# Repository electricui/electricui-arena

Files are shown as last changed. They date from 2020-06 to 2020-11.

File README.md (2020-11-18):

# Electric UI CI Arena
Hardware for continuous integration testing of serial interfaces and microcontrollers. [Background and more detailed discussion outlined in this blog post](https://electricui.com/blog/hardware-testing).

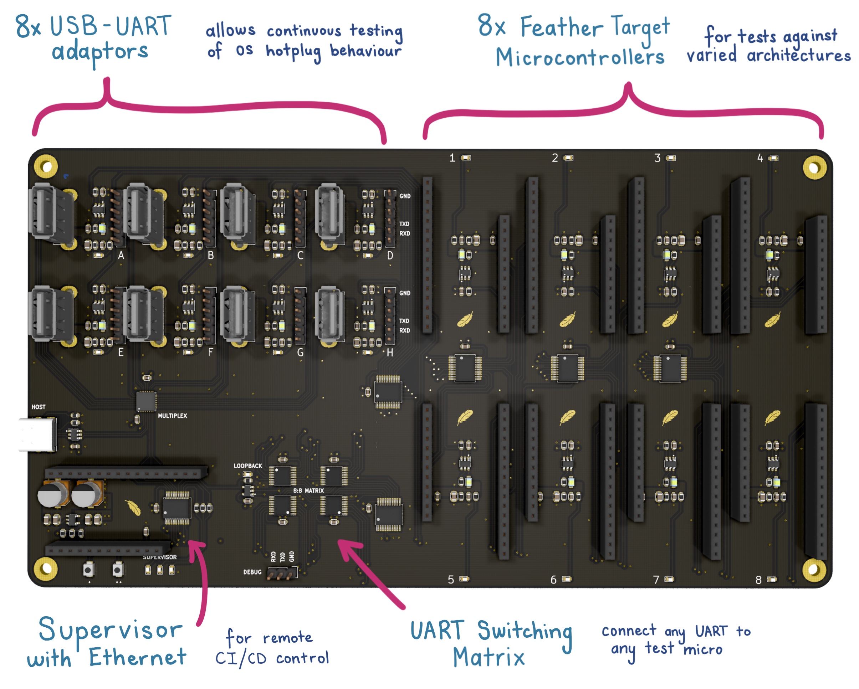
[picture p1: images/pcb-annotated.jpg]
PCB Render with annotations


The board (KiCAD files in `/hardware`) exposes control to a CI build worker to power up any of the USB-UART adaptors in either loopback mode, or connected to any **one** of the hardware targets for a total test matrix of 72 combinations. 

Intended to run tests for hot-plug detection (by controlling the mux or USB power control), disconnection handling (by re-routing serial to the void) and to validate a wide range of microcontroller architectures and their corresponding toolchains.

## USB to UART Validation

Up to 8 USB ports are provided behind a USB mux from the host.

Individual power switching is available per-port, with optional routing of the USB-UART adaptor's serial lines to either loop-back, or to one of the target microcontrollers.

The following adaptors are used as test adaptors:

- [FT232RQ](https://www.sparkfun.com/products/9717)
- PL2303
- [CP2012](https://www.adafruit.com/product/954)
- CH340G

In the future, we hope to add Bluetooth/WiFi adaptors for wireless tests against compatible targets.

## Microcontroller Validation

8 power-switched targets are supported with connections to hardware serial. The [Adafruit Feather specification](https://learn.adafruit.com/adafruit-feather/feather-specification) is used, as a majority of planned targets are available in Feather format.

The following boards are used as test devices:

- [ATMEL 328P](https://www.adafruit.com/product/3458)
- [ATMEL SAMD21G](https://www.adafruit.com/product/2772)
- [ST STM32F405](https://www.adafruit.com/product/4382) with CubeHAL
- [Nordic nRF52840](https://www.adafruit.com/product/4516) 
- [RISC-V FE310](https://www.sparkfun.com/products/15799) with Zephyr RTOS
- [Ambiq Apollo3 ARM-M4F (Sparkfun Artemis)](https://www.sparkfun.com/products/15574) 
- [Espressif ESP32](https://www.sparkfun.com/products/15663) with ESP-IDF
- [Teensy 3.2](https://www.pjrc.com/store/teensy32.html) & [Teensy-Feather adaptor](https://www.adafruit.com/product/3200) with Arduino

Test hardware will be flashed with a mix of native 'bare metal' images, and at least one target will act as validation of the Arduino framework.

When populating the test Feather boards with headers, use 'stacking' headers to allow for future sensor/display additions to targets.

## Supervisory Control

An additional Feather is provided to act as the supervisor. This connects to the CI server using a [ethernet featherwing](https://www.adafruit.com/product/3201).

The supervisor (through I2C expanders) controls power switches to each of the serial adaptors and test devices, and has 2 IO lines to each microcontroller to allow for input/output checks.

An analog line is shared across all modules, with the intent of using the supervisor's DAC output, allowing additional tests.

Firmware is in `/firmware`

# Manufacture

- I used JLPCB's 4-layer JLC7628 controlled impedance process.
- No stencil was ordered, as 2 units with low SMD part count is easy enough to paste by hand.
- All components were available from Digikey.
- Microcontroller targets were bought from Sparkfun and Adafruit (via Digikey)
- Assembled per board costs just under $100AUD.
- Loaded price (with listed microcontrollers, USB-serial adaptors, supervisor w ethernet) approx $500AUD.

See `/hardware/output/arena-BOM.html` for PCB BOM.

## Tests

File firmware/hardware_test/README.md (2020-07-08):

# Arduino Firmware Notes

Written against a [Adafruit ESP32 Feather](https://www.adafruit.com/product/3405), and [Adafruit Ethernet Featherwing](https://www.adafruit.com/product/3201) with the backplane PCB in this repo.

A reasonably thin GPIO abstraction layer maps enum named pins to the expander and pin on the board.

## Fimware Deps

A from-scratch driver for the MCP23008 I2C expanders is included in the sources instead of pulling a 3rd party one.

All 3rd party dependancies are for networking.

### Ethernet 

The ethernet Featherwing uses the [Arduino `Ethernet` library](https://github.com/arduino-libraries/Ethernet) which can be installed through the Arduino IDE board manager.

Due to an upstream `esp32-arduino-core` [change](https://github.com/arduino-libraries/Ethernet/issues/88), `EthernetServer` fails to build with the following error:

```
 error: cannot declare variable 'server' to be of abstract type 'EthernetServer'
```

I applied the changes [outlined in this open PR](https://github.com/arduino-libraries/Ethernet/pull/107/commits/81c2ce0c6922fc984703bf3adeacaf73bcc3f578).

### mDNS / Bonjour

Uses the [EthernetBonjour](https://github.com/TrippyLighting/EthernetBonjour) library.

### HTTP/REST

This [HTTPserver](https://github.com/nickgammon/HTTPserver) library makes handling the REST style API a bit less painful.

### Config Storage

User-configurable settings are maintained on the ESP32 supervisor micro using `Preferences.h` which is provided alongside the rest of the ESP32 hal.

# API Documentation

Valid requests will return as `200 OK`, with relevant text in the body, typically echoing the request.

If an invalid request is made, a `500 Internal Server Error` will be returned with some debug text in the body.

All data for GET or POST is assumed to be string formatted.

## Requests

Purely used to query the board for information.

| GET URL | Description | Response |
| --- | --- | --- |
| `arena.local/loopback?` | Serial Matrix Loopback enabled | `true`/`false` |
| `arena.local/adapter?` | List the stored human-friendly USB adapters | `a, ftdi`<br />`b, cp2012`<br />...<br />`h, pl232` |
| `arena.local/adapter?b` | Human-friendly name of a specified adapter | `ch340` |
| `arena.local/adapter?ch340` | Board labelled name of a human-readable adapter name | `b` |
| `arena.local/target?` | List the stored human-friendly device names | `1, riscv`<br />`2, stm32`<br />...<br />`8, avr` |
| `arena.local/target?2` | Human-friendly name of a specified target | `stm32` |
| `arena.local/target?stm32`  | Board labelled name of a human-readable target name  | `2` |
| `arena.local/config?name` | Get the name of the test board | `Arena Testbed` as default, otherwise a string as configured. |

## Control

HTTP POST are used to set the active adapter, target, and loopback mode. The data/payload is assumed to be string formatted.

When setting a target or adapter, the firmware will automatically setup the relevant side of the USB mux, power control, and serial matrix routing as required.

| POST URL | Data | Description | Response |
| --- | --- | --- | --- |
| `arena.local/adapter`  | `ft232` | Select the active USB Serial adapter by human-readable name | `ft232` |
| `arena.local/adapter`  | `a` | Select the active USB Serial adapter by board-label | `a` |
| `arena.local/adapter`  | `a=ft232` | Sets the human-readable name of `a` to `ft232` | `Adapter name set` |
| `arena.local/target` | `stm32` | Select the active test device by human-readable name | `stm32` |
| `arena.local/target` | `3` | Select the active test device by board-label | `3` |
| `arena.local/target` | `1=riscv` | Sets the human-readable name of `1` to `riscv` | `Device name set`  |
| `arena.local/loopback` | `true` | Enable the serial loopback switch | `true` |
| `arena.local/loopback` | `false` | Disable the serial loopback switch | `false` |
| `arena.local/config` | `name=Dave` | Sets the board's name to `Dave` | `Board name set` |

## Examples

- Select the 8th target device: `curl -X POST http://arena.local/target -d 8`

- Select a target called stm32: `curl -X POST http://arena.local/target -d stm32`

- Configure the human-readable name for the 2nd target to be `teensy`: `curl -X POST http://arena.local/target -d 2=teensy`

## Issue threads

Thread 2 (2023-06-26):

Link to order the assembled PCB

gshiva, 2023-06-26:
For people who find it hard to do the "simple" paste and heat of SMD components, it would be great if we have a link where we can order the preassembled board from JCB.

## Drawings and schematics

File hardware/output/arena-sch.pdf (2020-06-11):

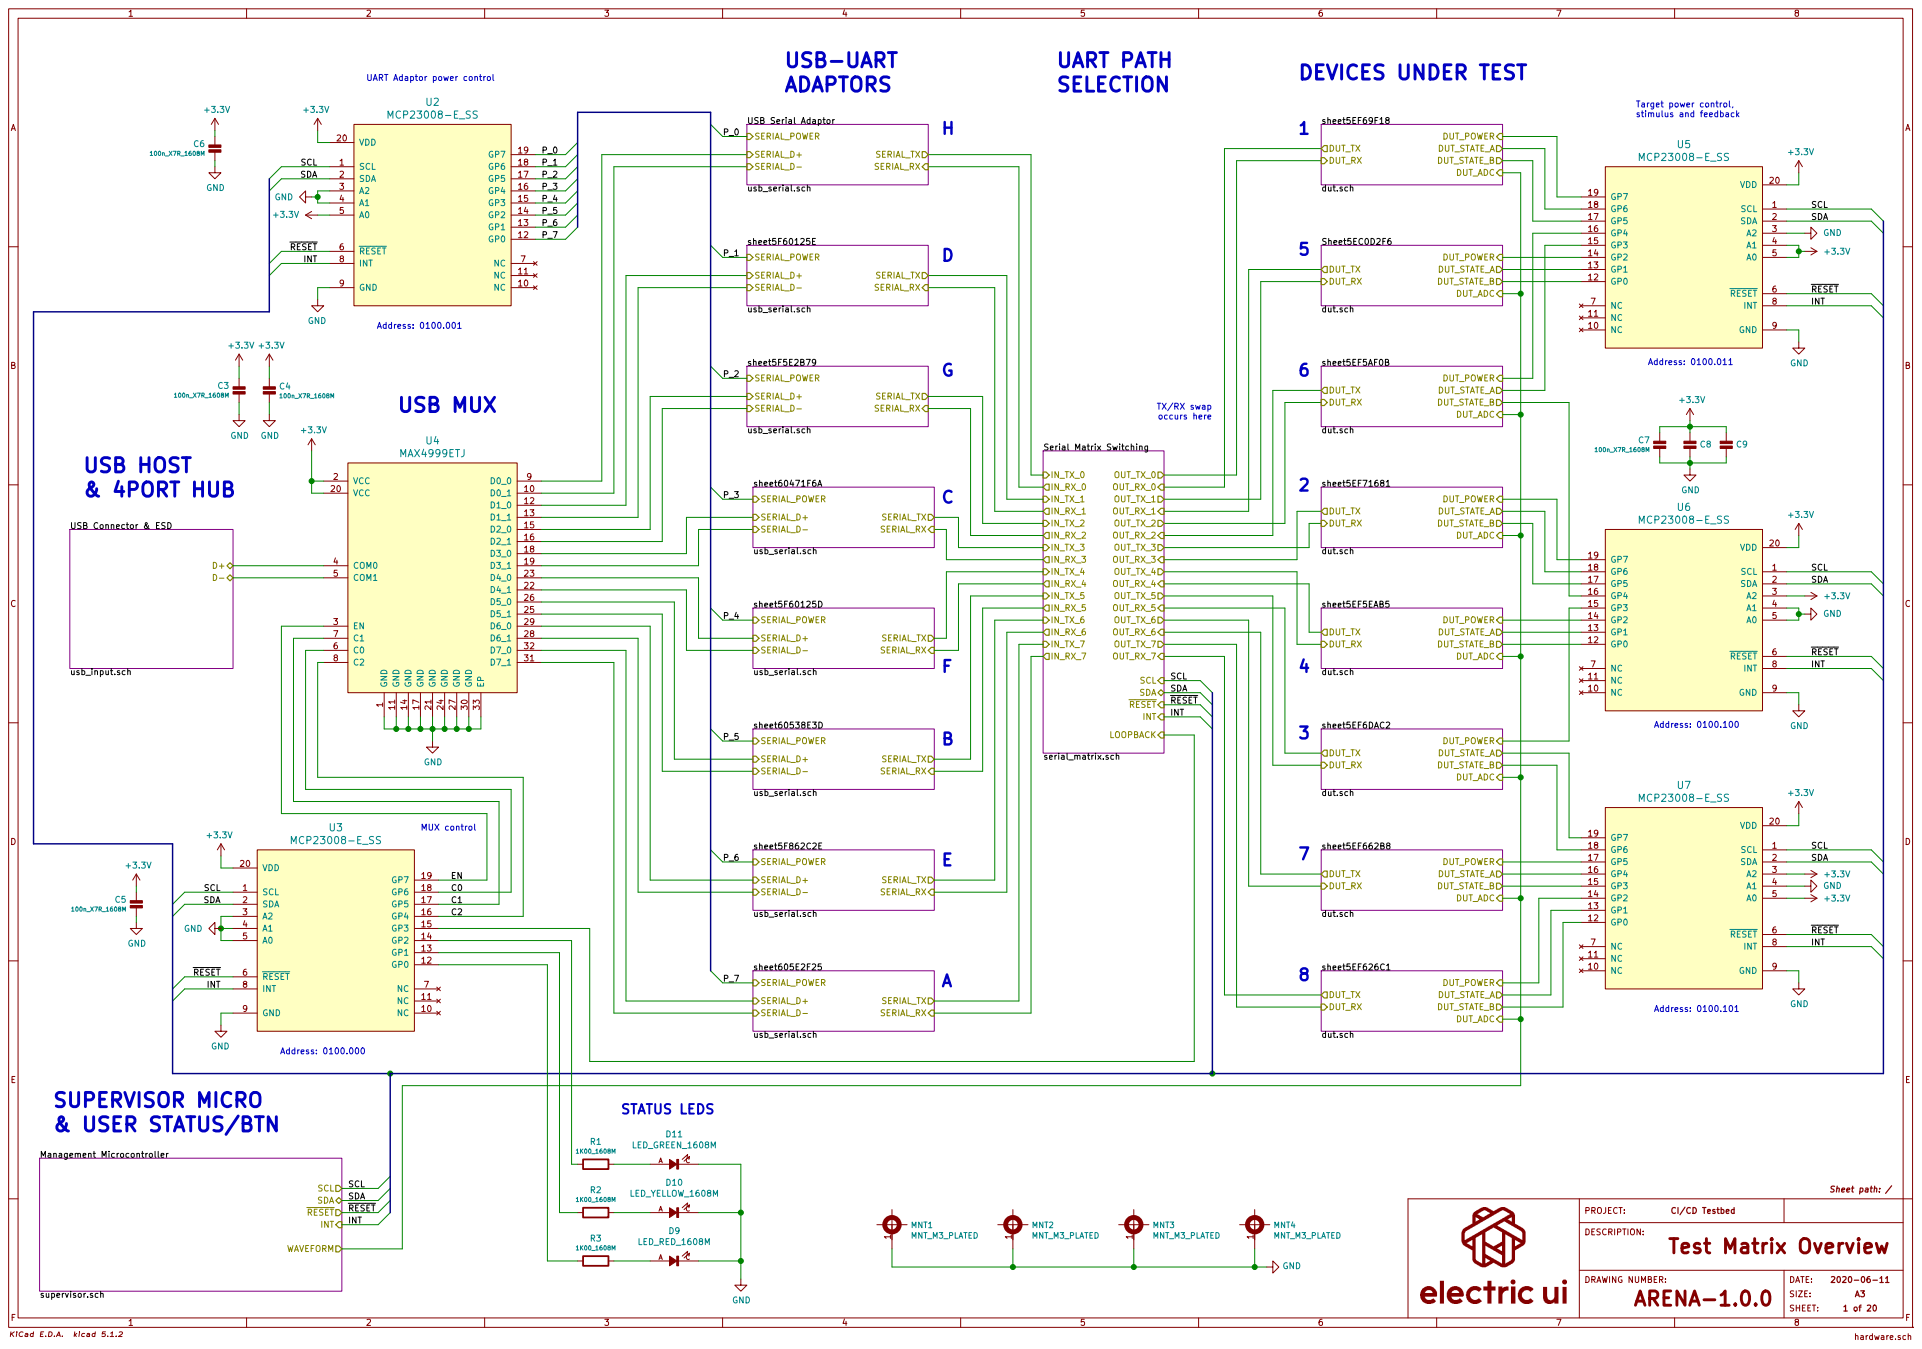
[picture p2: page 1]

DEVICES UNDER TEST UART PATH
SELECTION
SERIAL_RX USB Serial Adaptor usb_serial.sch SERIAL_POWER

ADAPTORS GND
Target power control, stimulus and feedback UART Adaptor power control

Address: 0100.101 Address: 0100.100 Address: 0100.011 SUPERVISOR MICRO

1 D0_1 10 GND 11 D1_0 12 D1_1 13 GND 14 D2_0 15 D2_1 16 GND 17 D3_0 18 D3_1 19 VCC 2 VCC 20 GND 21 D4_1 22 D4_0 23 GND 24 D5_1 25 D5_0 26 GND 27 D6_1 28 D6_0 29 EN 3 GND 30 D7_1 31 D7_0 32 EP 33 COM0 4 COM1 5 C0 6 C1 7 C2 8 D0_0 9 U4 MAX4999ETJ C4

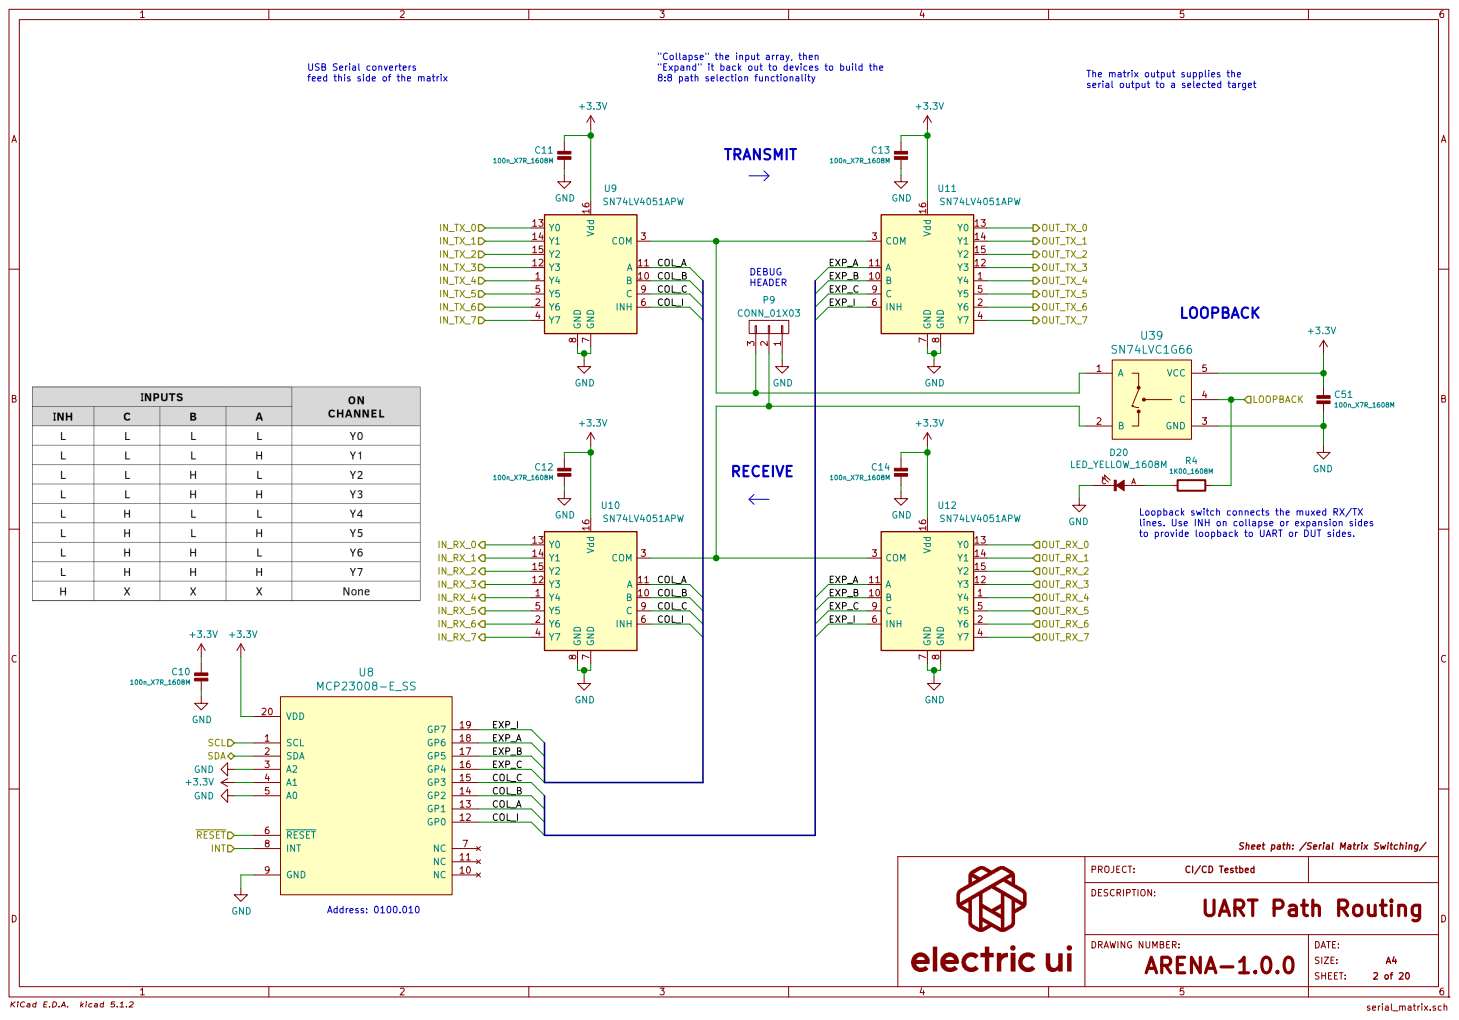
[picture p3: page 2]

"Collapse" the input array, then
"Expand" it back out to devices to build the
8:8 path selection functionality

serial output to a selected target USB Serial converters
feed this side of the matrix

The matrix output supplies the

Loopback switch connects the muxed RX/TX
lines. Use INH on collapse or expansion sides

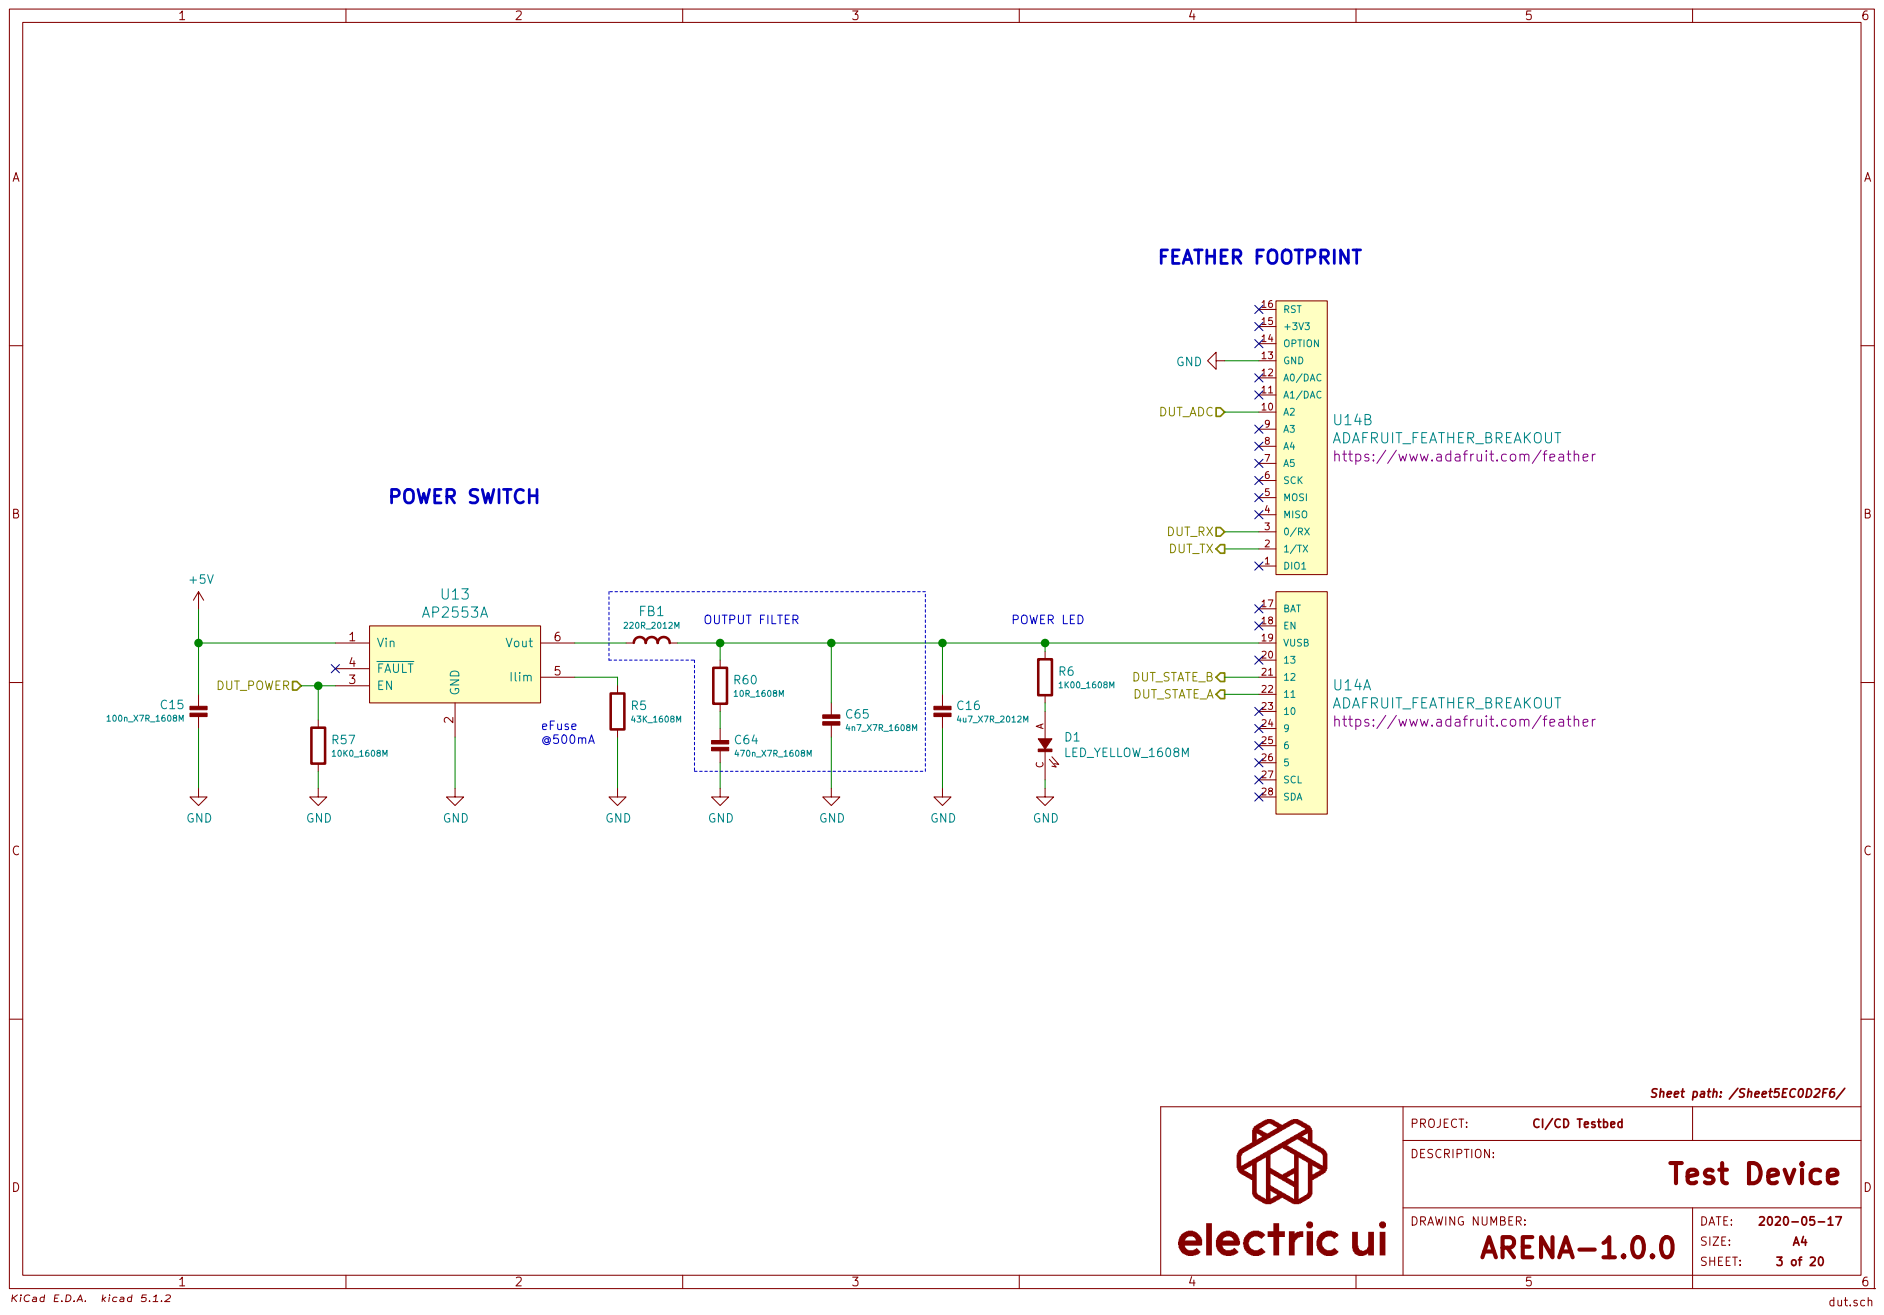
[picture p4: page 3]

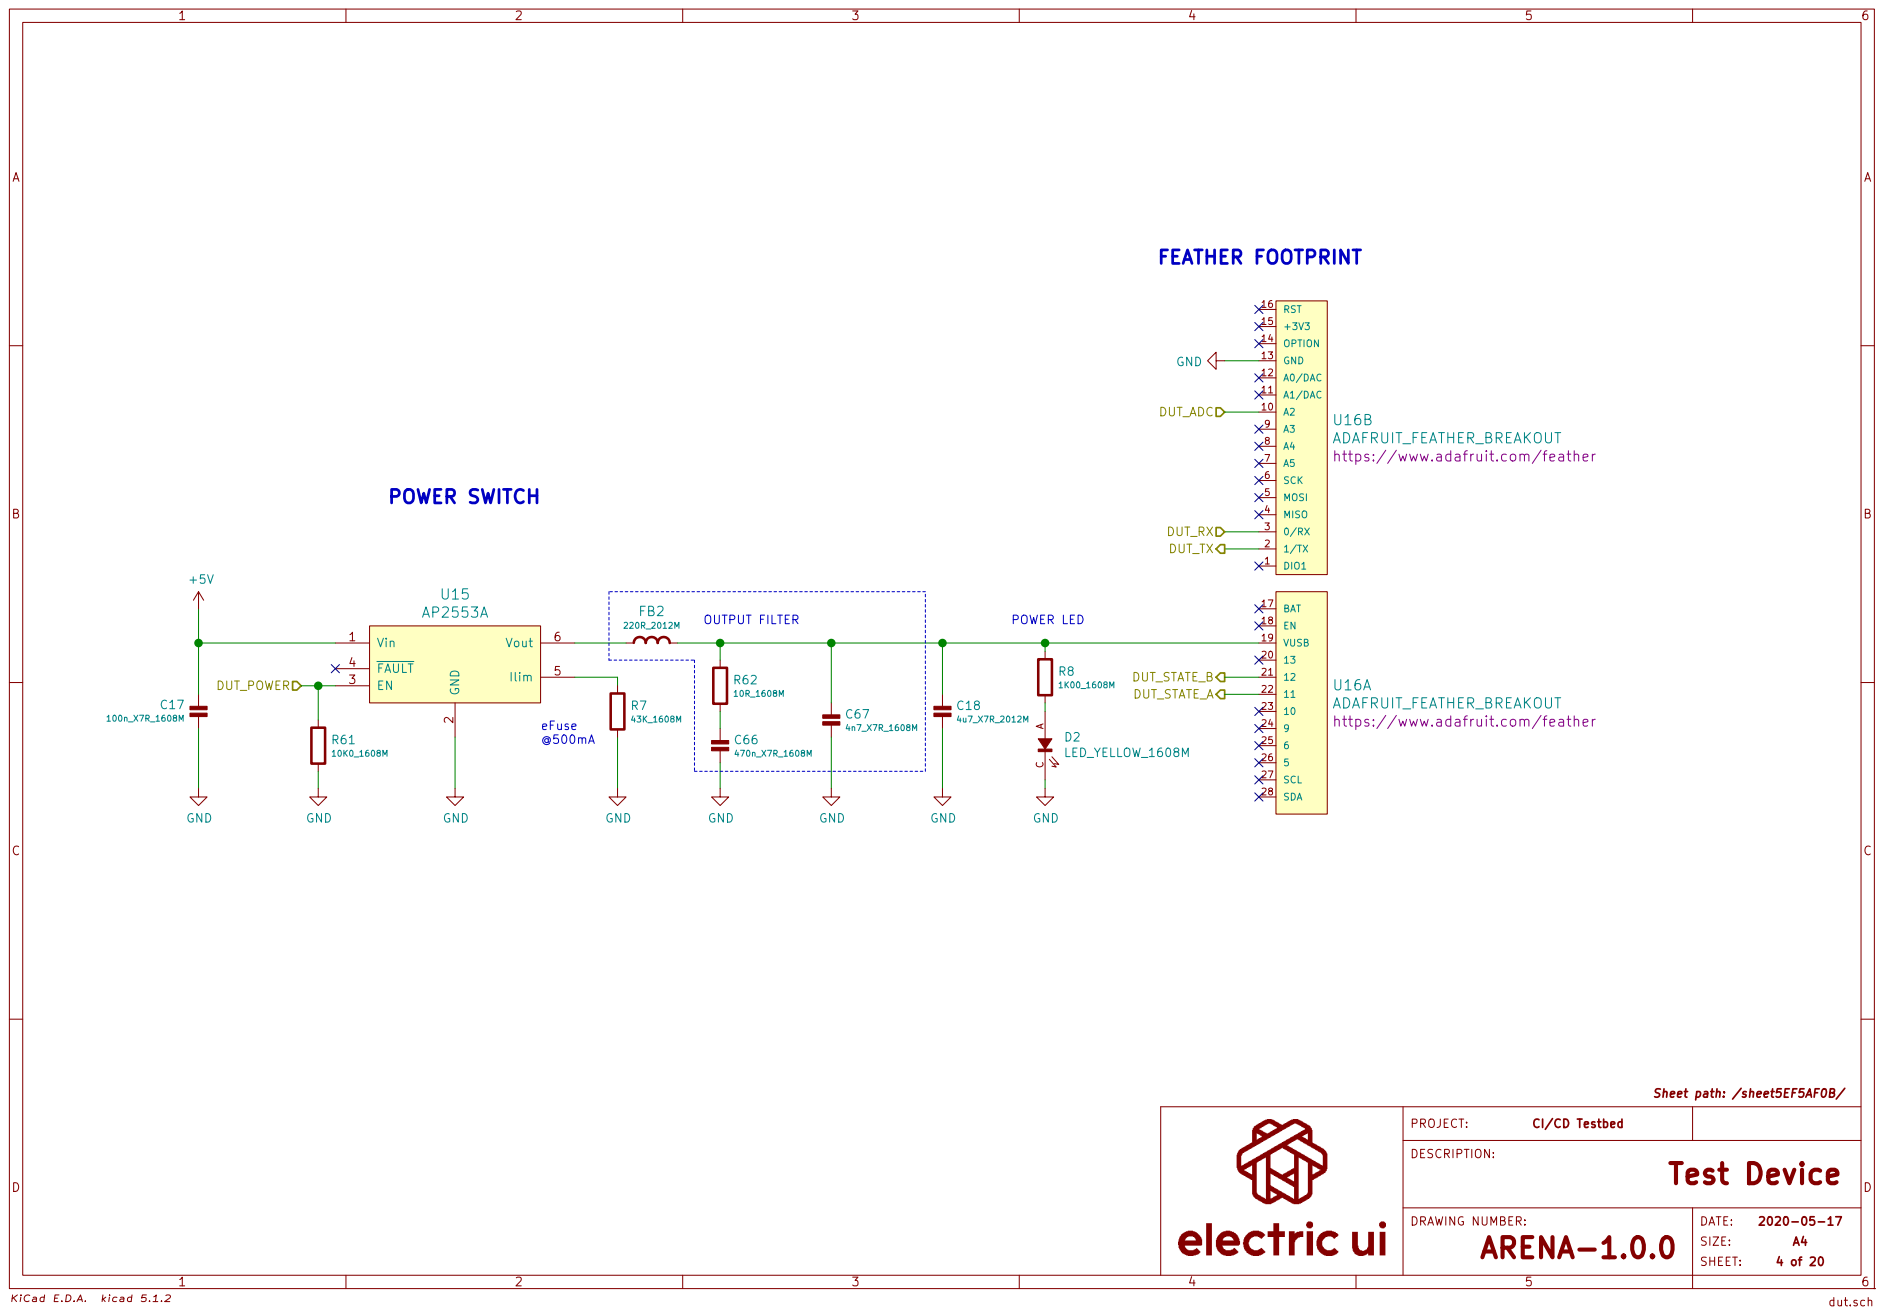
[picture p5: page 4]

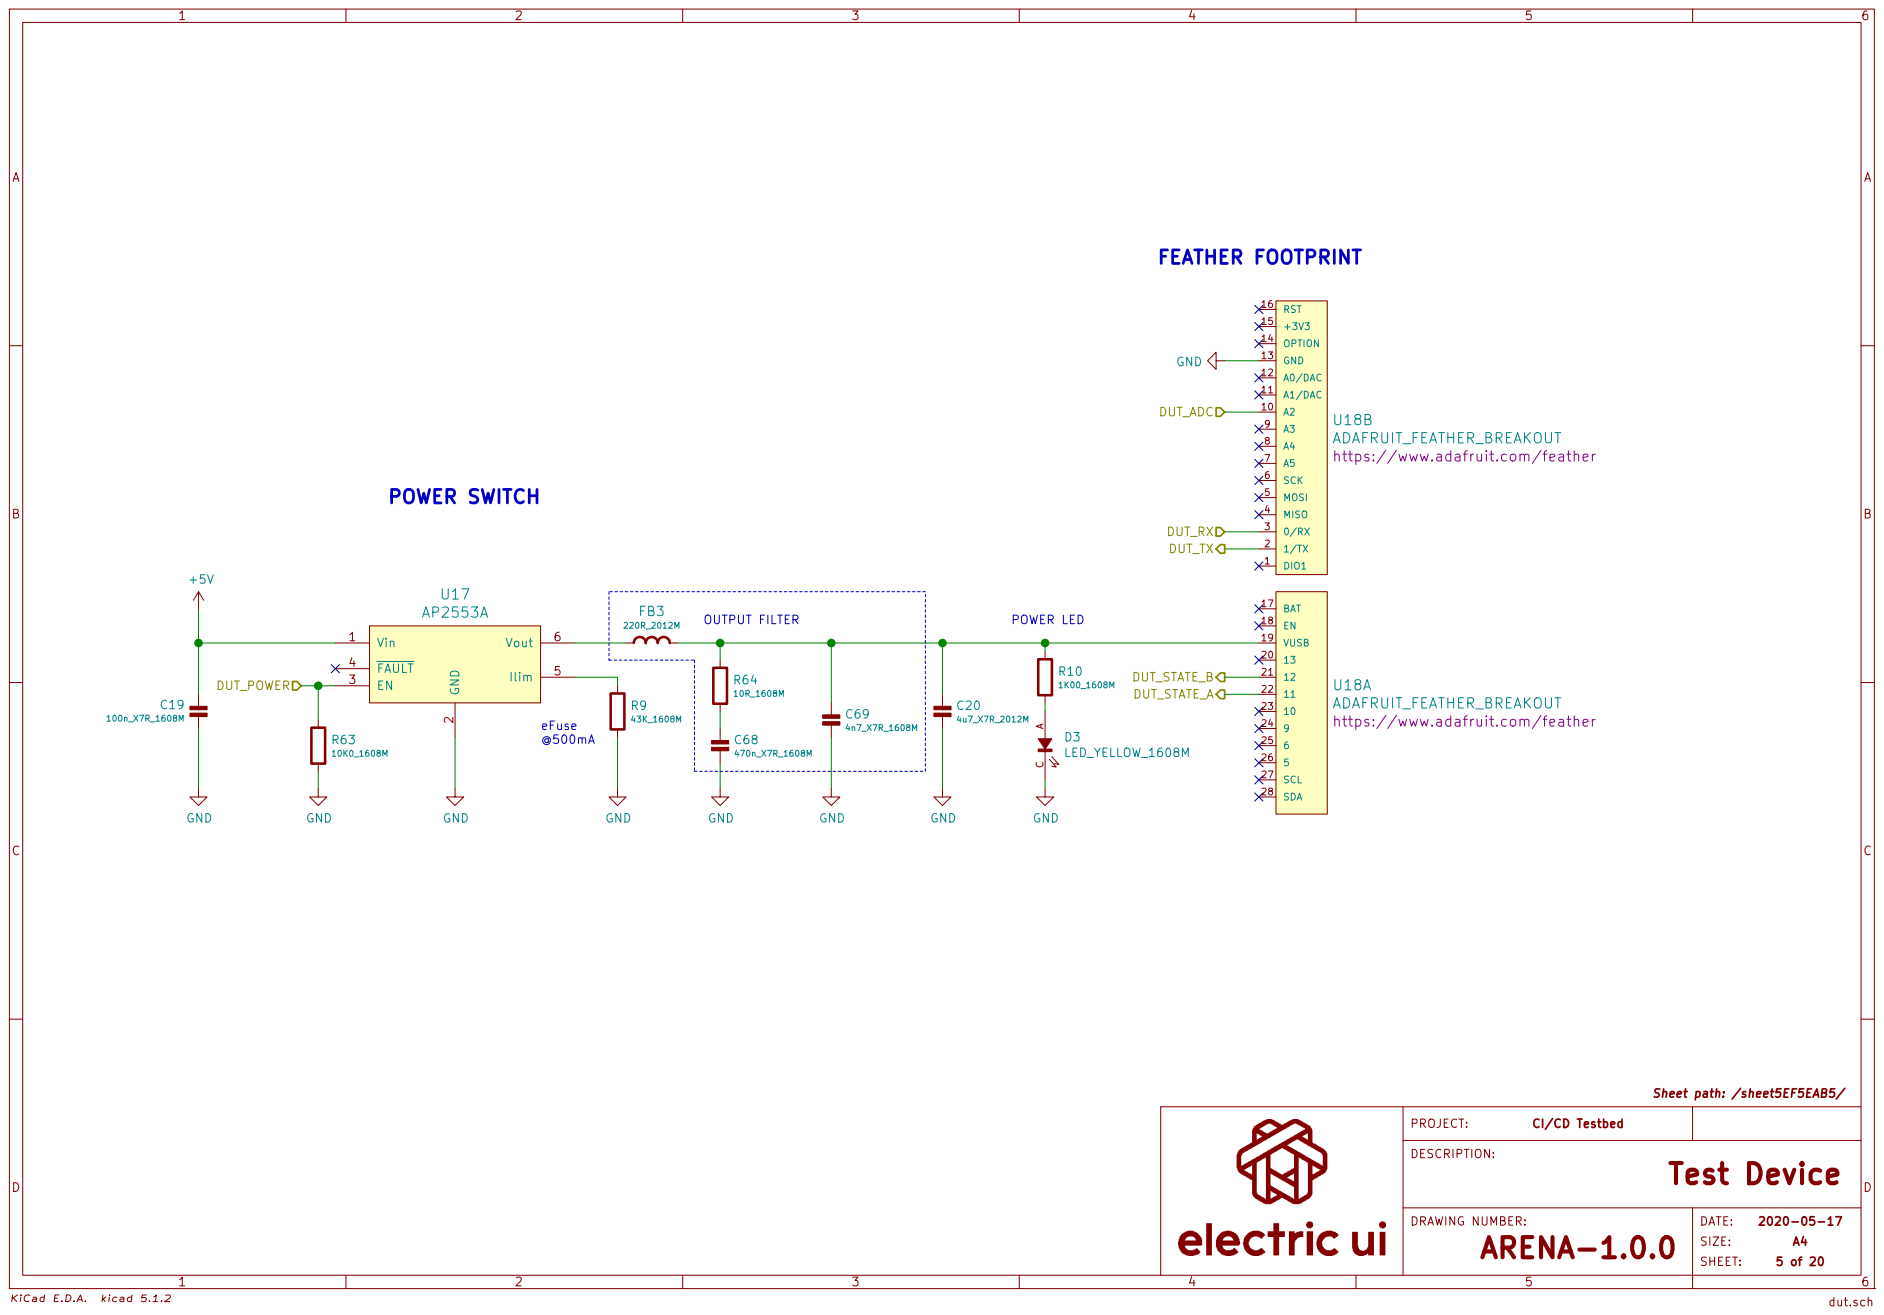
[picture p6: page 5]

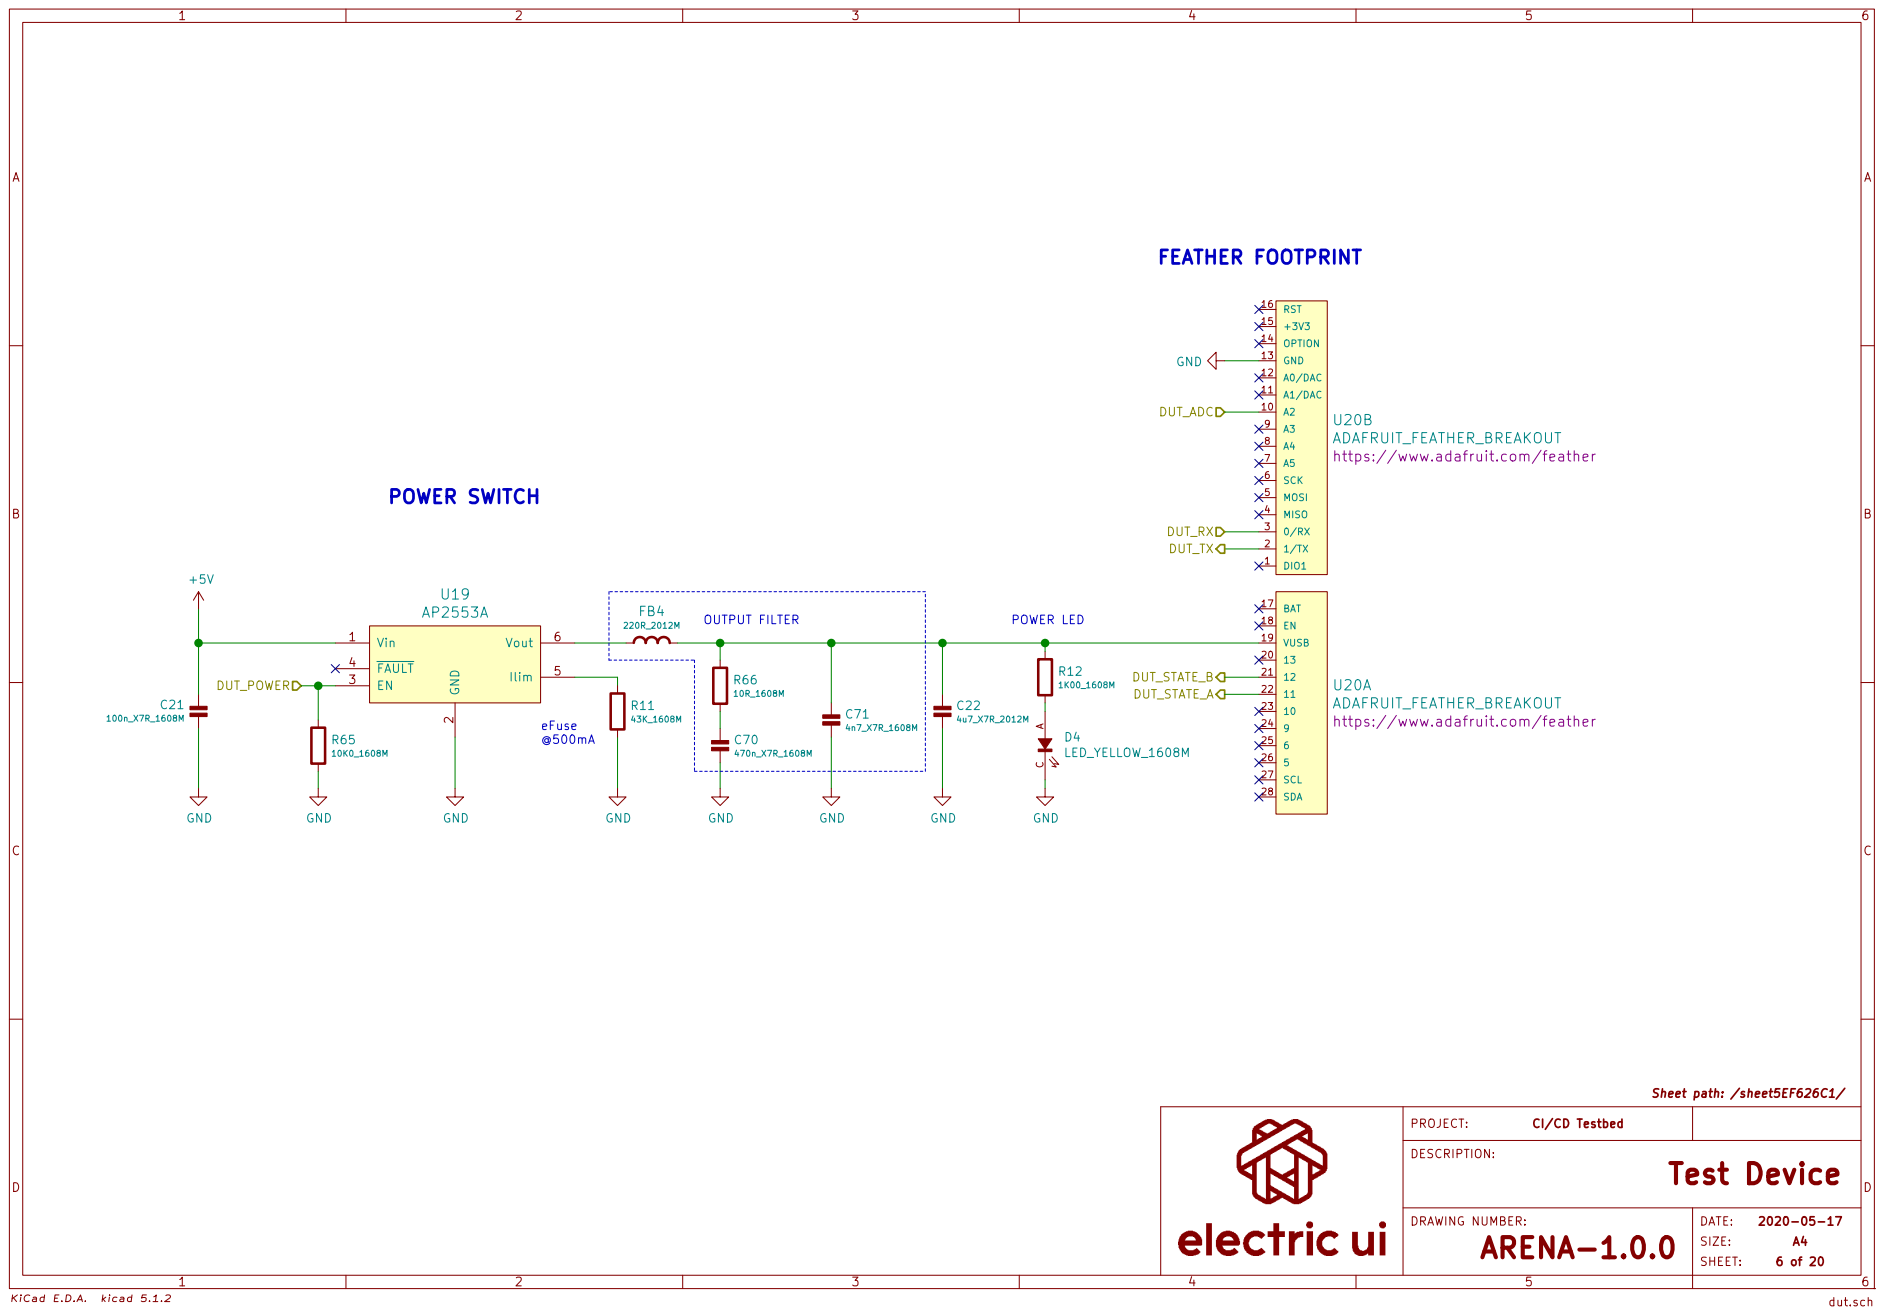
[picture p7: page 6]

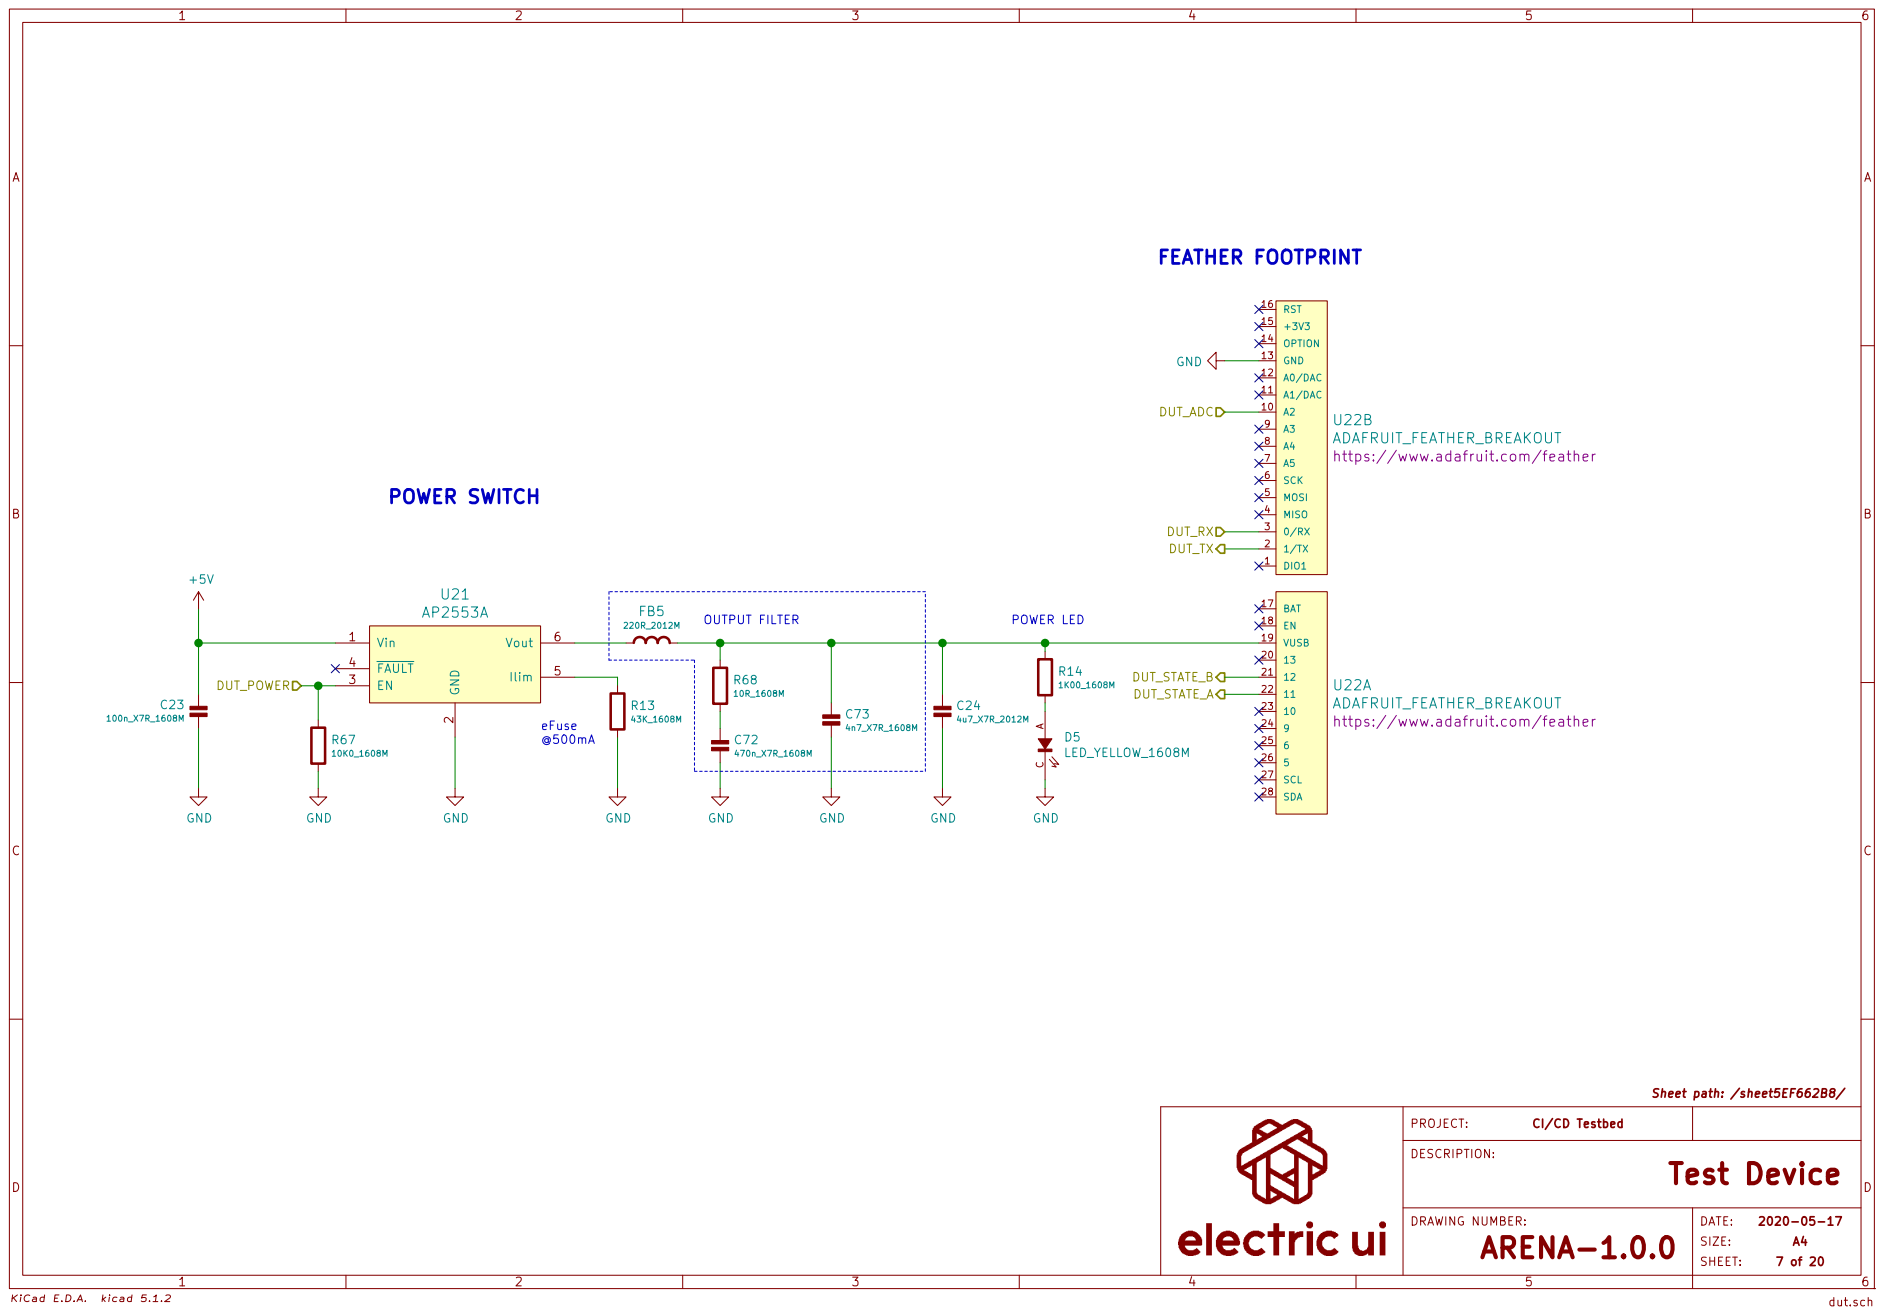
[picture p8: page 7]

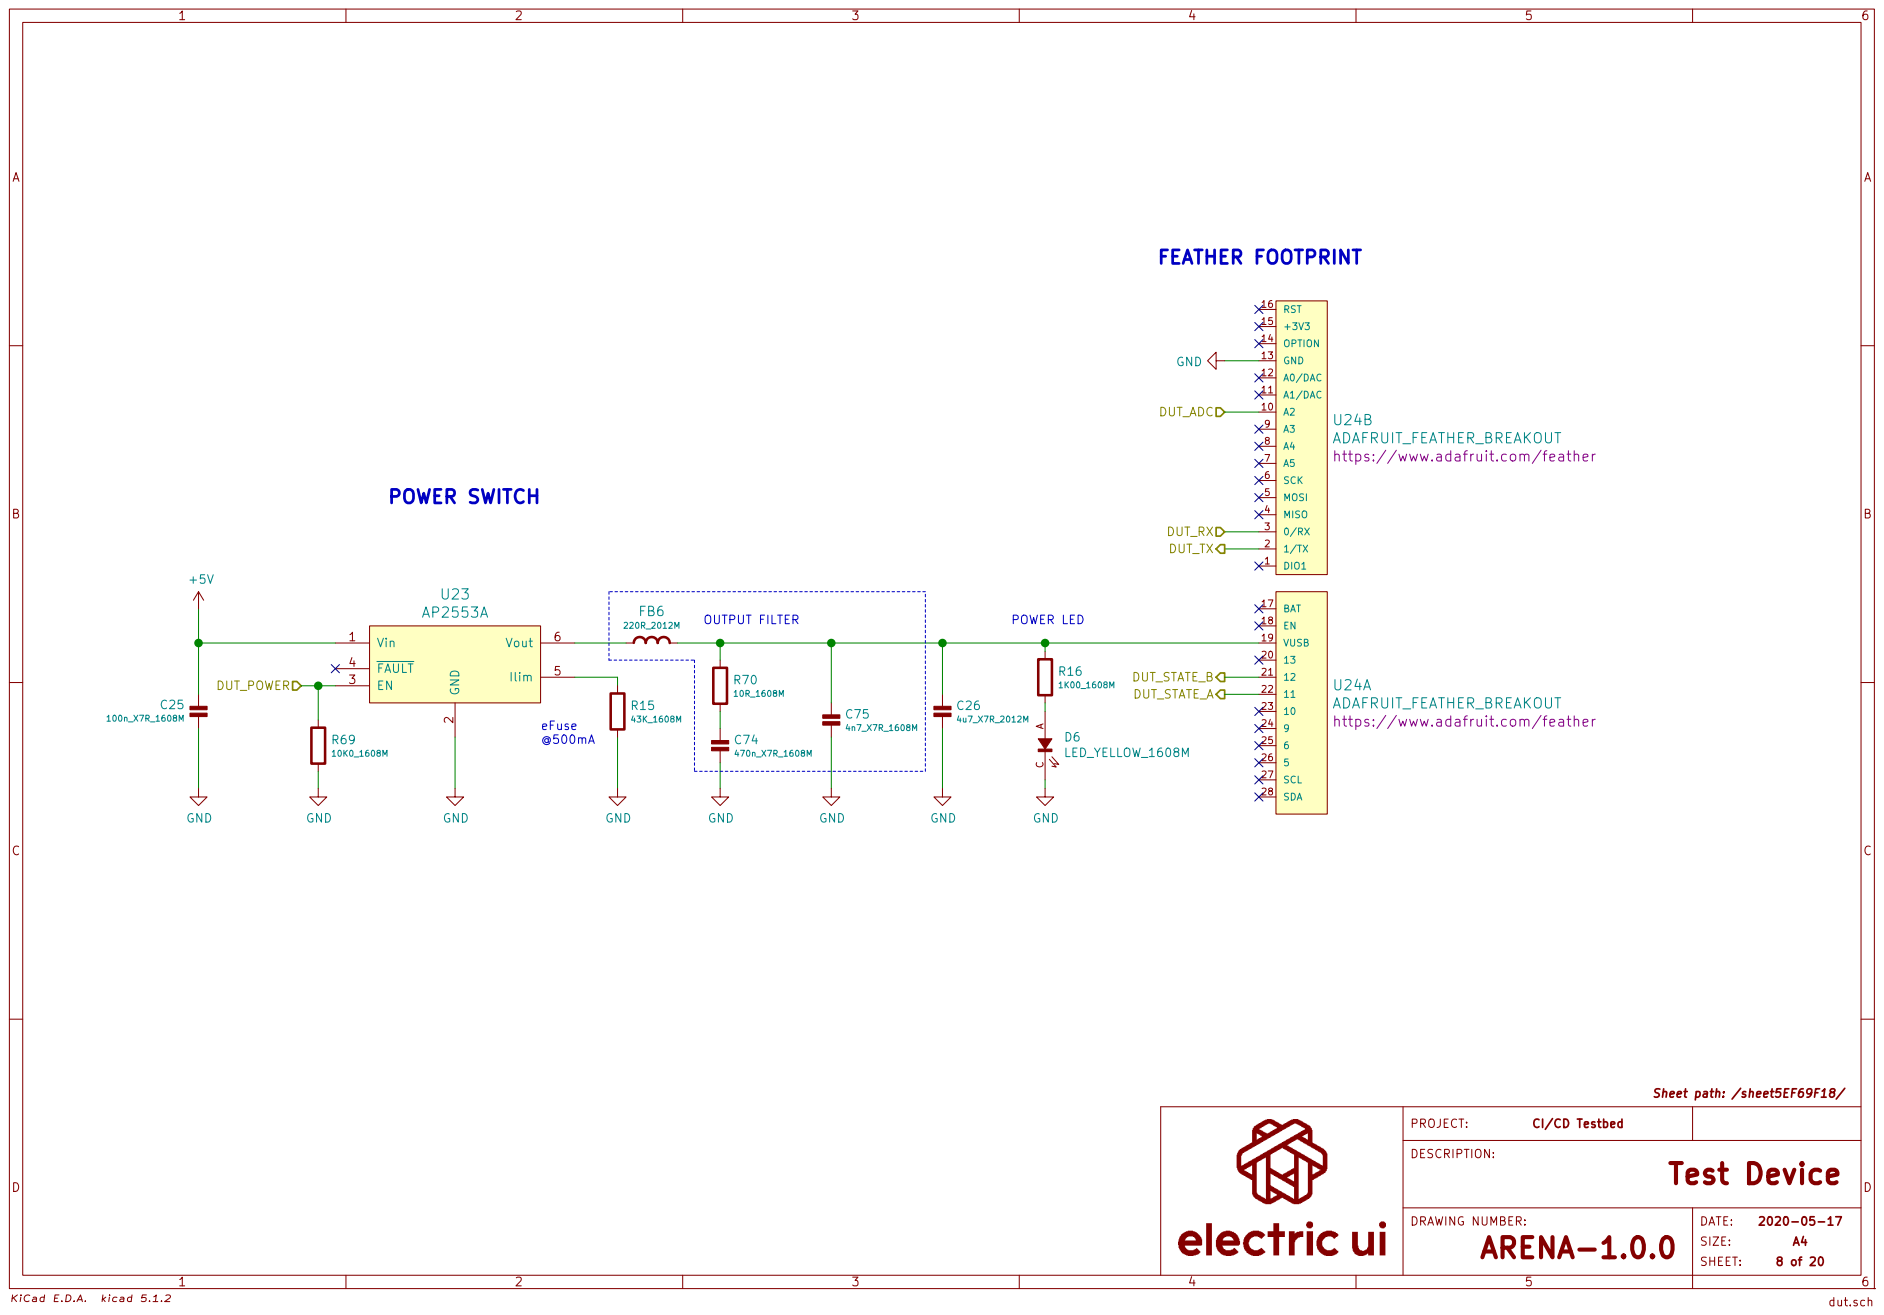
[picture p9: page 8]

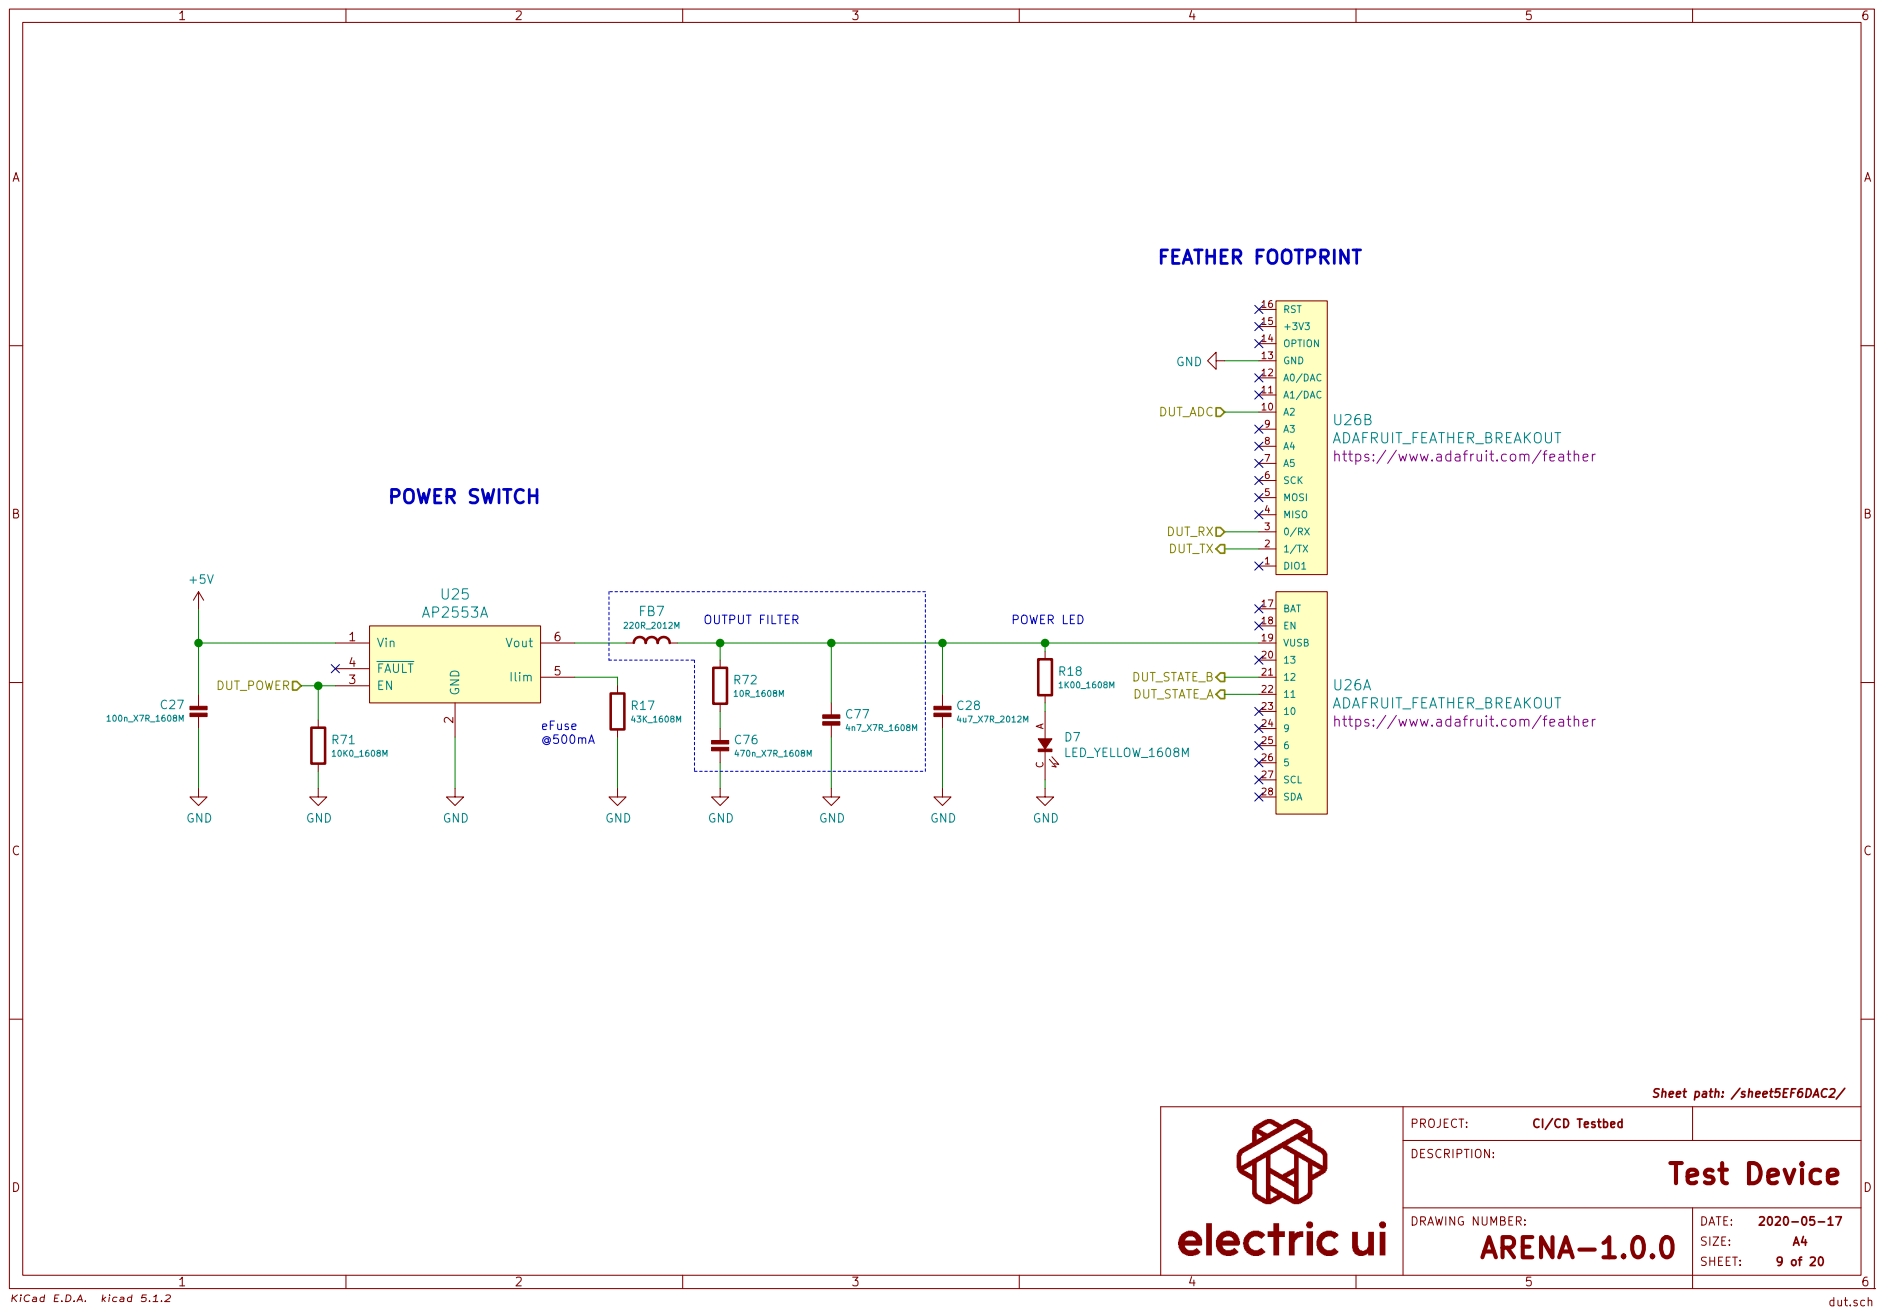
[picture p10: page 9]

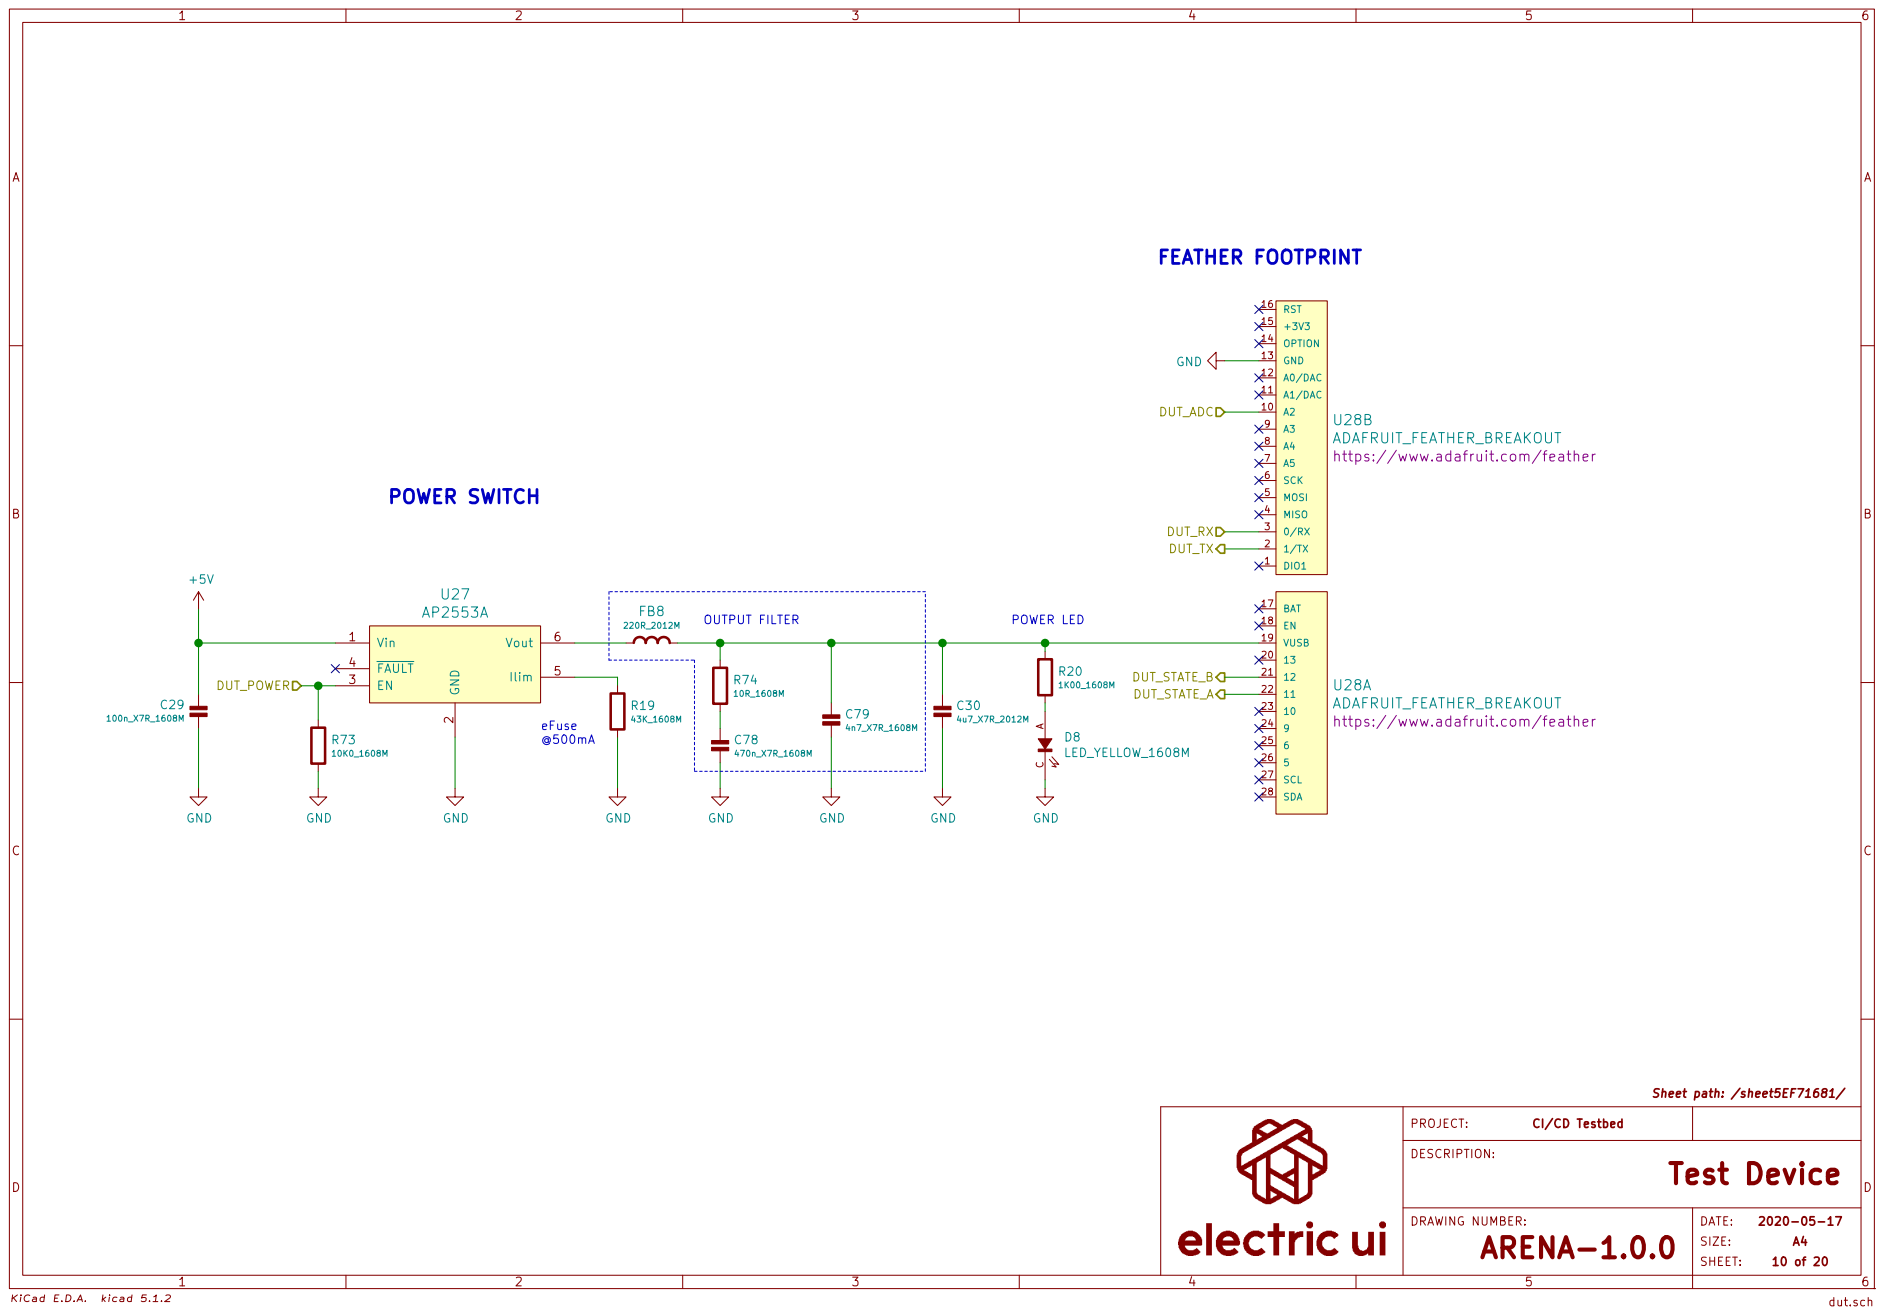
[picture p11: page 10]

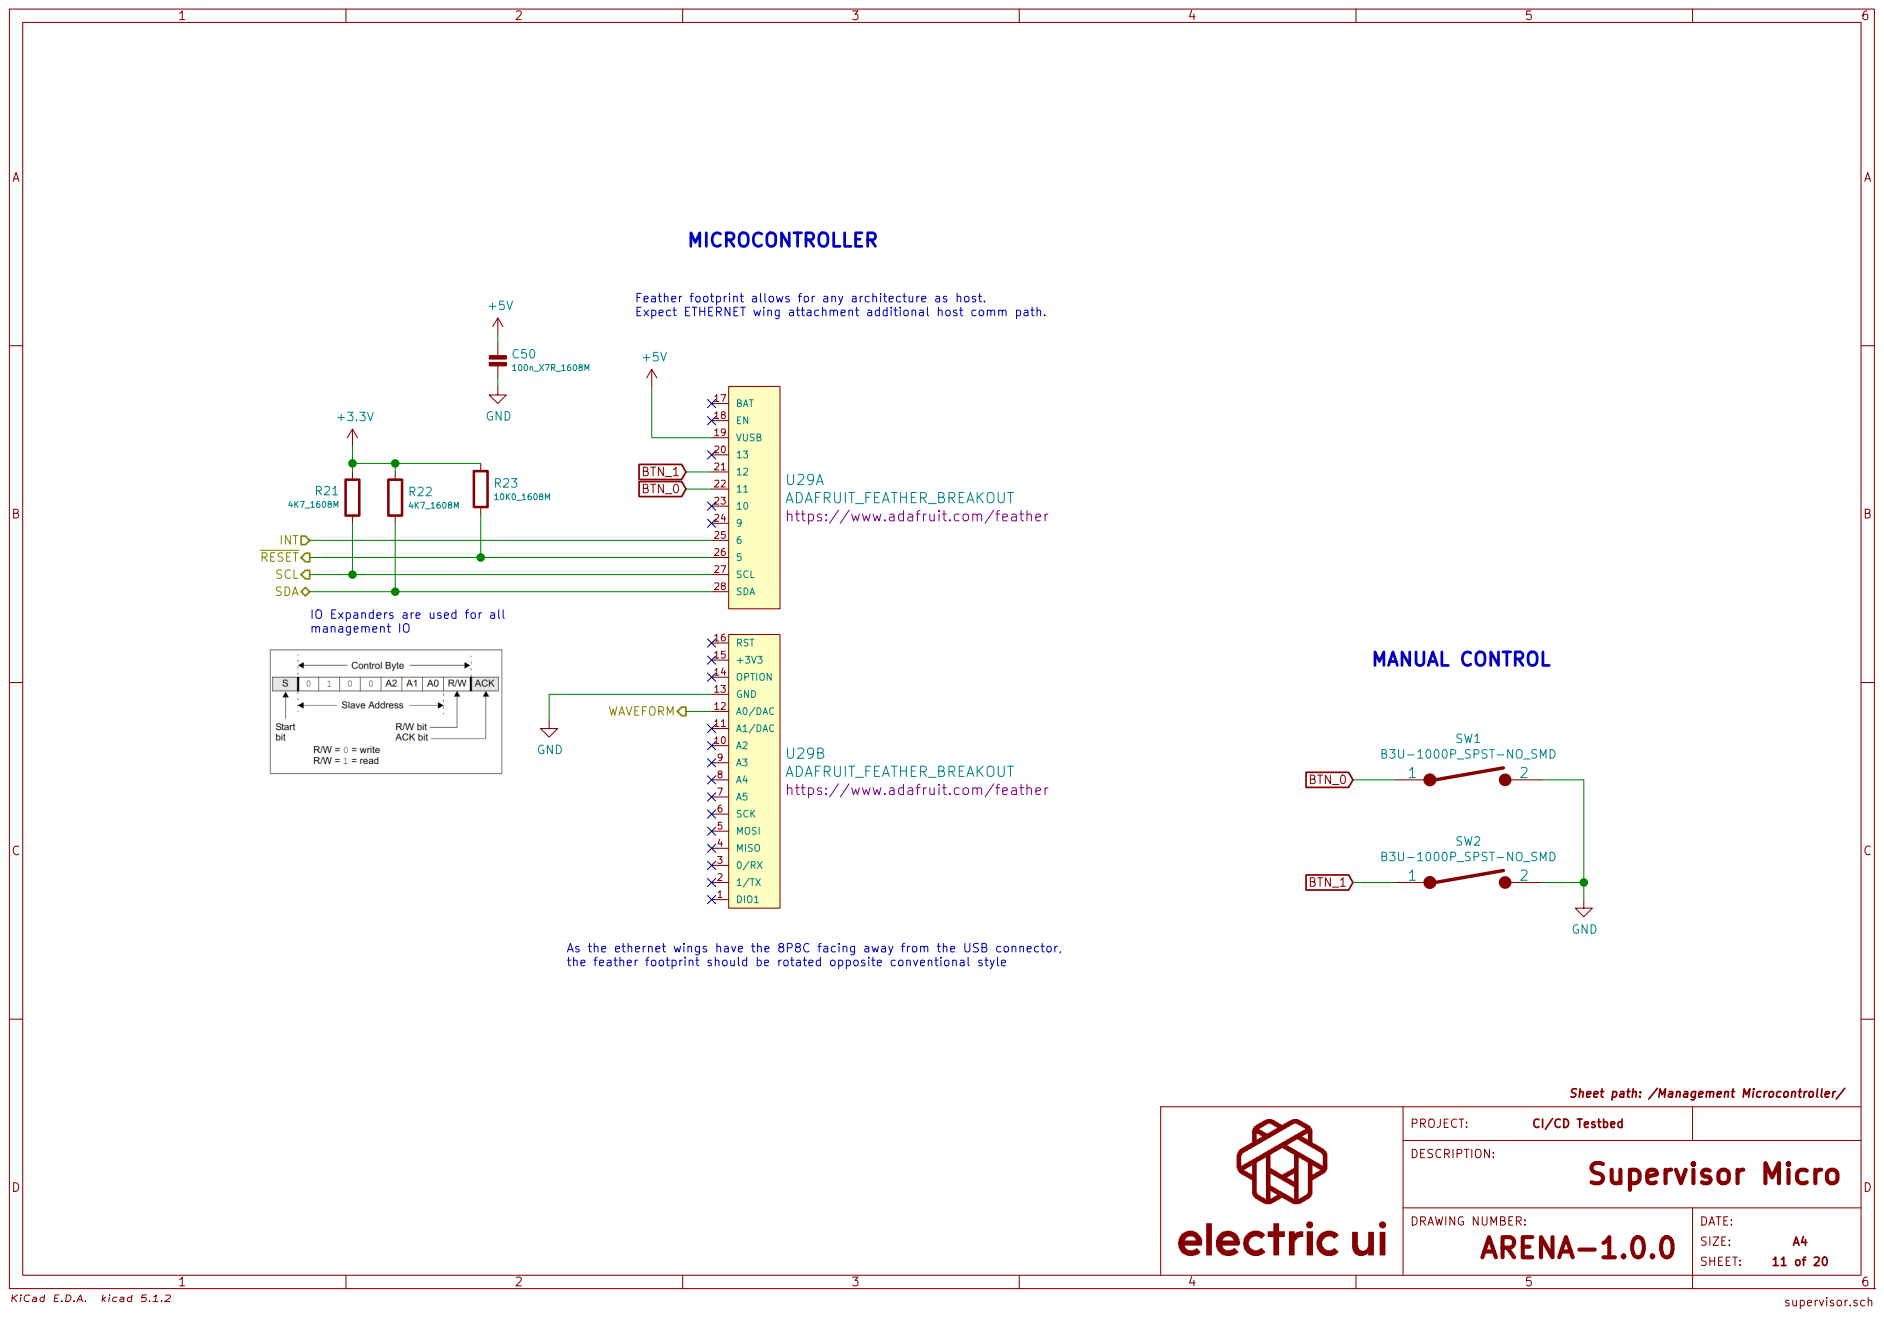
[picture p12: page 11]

Feather footprint allows for any architecture as host.

Expect ETHERNET wing attachment additional host comm path. R22

INT
https://www.adafruit.com/feather SCL SDA RESET

IO Expanders are used for all
management IO

As the ethernet wings have the 8P8C facing away from the USB connector,

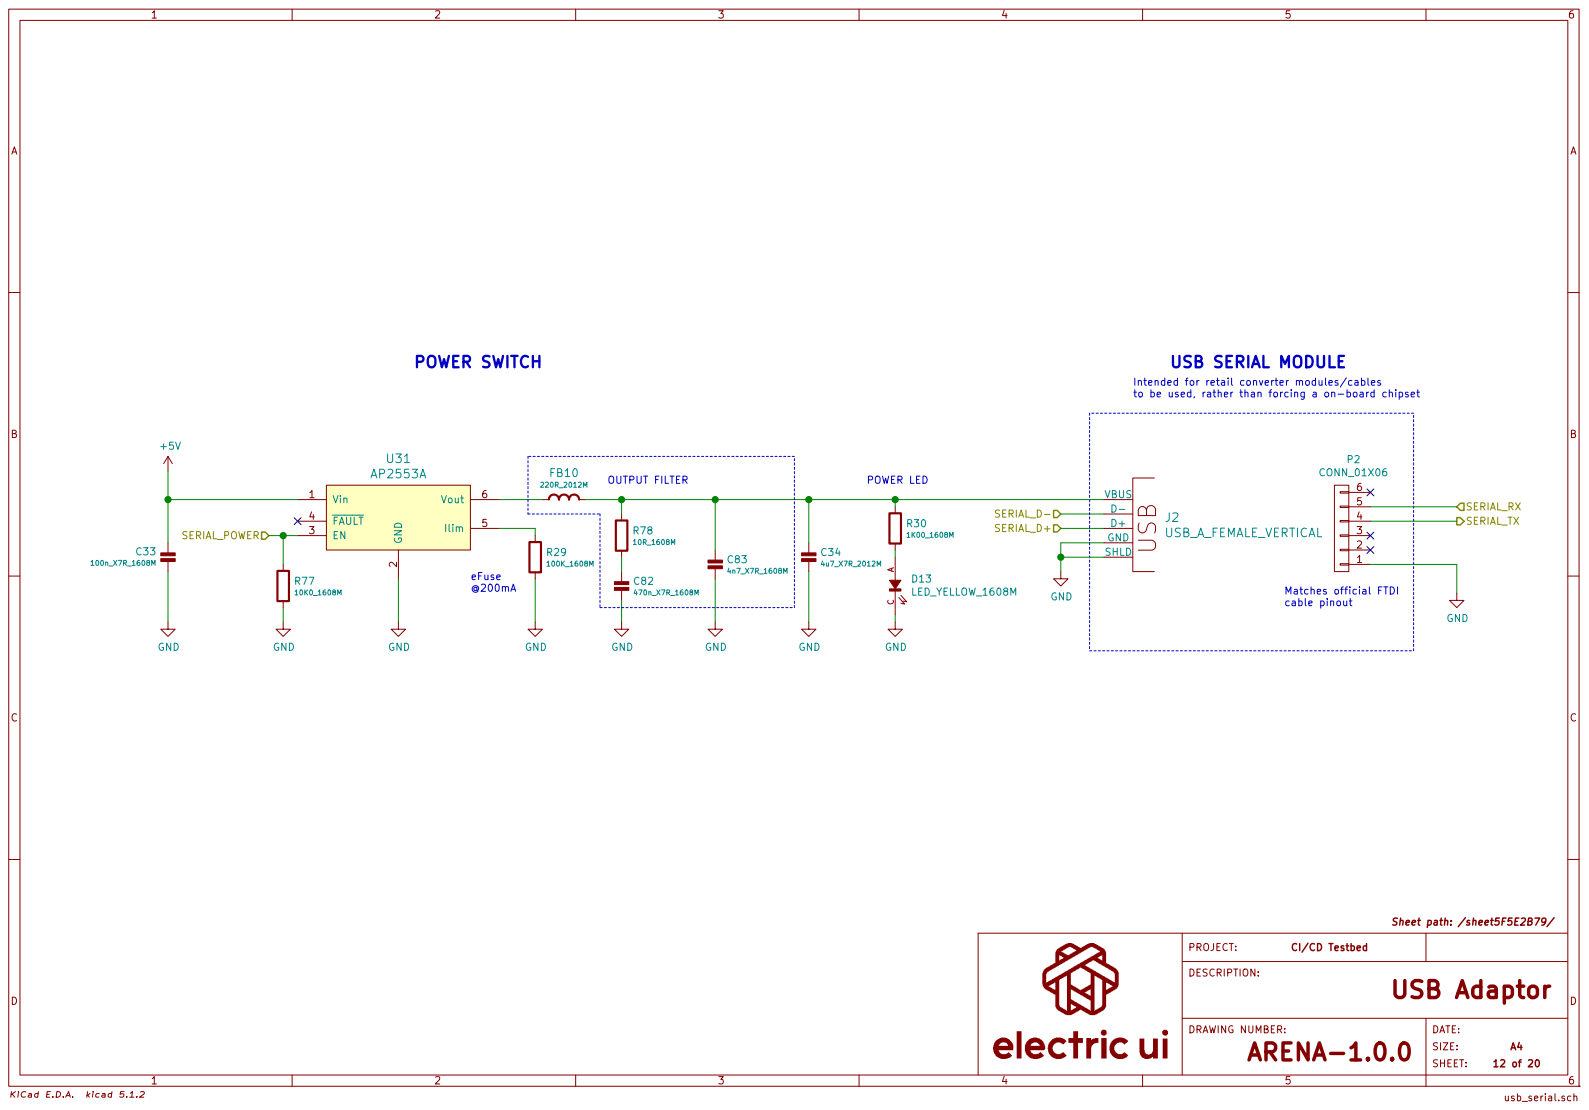
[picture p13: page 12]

to be used, rather than forcing a on-board chipset GND

Intended for retail converter modules/cables

6 P2 CONN_01X06 Matches official FTDI cable pinout USB
VBUS D- D+ GND


to be used, rather than forcing a on-board chipset GND

Intended for retail converter modules/cables

6 P3 CONN_01X06 Matches official FTDI cable pinout USB
VBUS D- D+ GND


to be used, rather than forcing a on-board chipset GND

Intended for retail converter modules/cables

6 P5 CONN_01X06 Matches official FTDI cable pinout USB
VBUS D- D+ GND


to be used, rather than forcing a on-board chipset GND

Intended for retail converter modules/cables

6 P7 CONN_01X06 Matches official FTDI cable pinout USB
VBUS D- D+ GND


to be used, rather than forcing a on-board chipset GND

Intended for retail converter modules/cables

6 P8 CONN_01X06 Matches official FTDI cable pinout USB
VBUS D- D+ GND


USBC makes it slightly easier to interop with macOS based CI/CD instances without USBA GND

Powers the USB mux, I2C IO expanders C63

2 EN 3 NC 4 VOUT 5 U1 AP2112K-3.3 GND


to be used, rather than forcing a on-board chipset GND

Intended for retail converter modules/cables

6 P6 CONN_01X06 Matches official FTDI cable pinout USB
VBUS D- D+ GND


to be used, rather than forcing a on-board chipset GND

Intended for retail converter modules/cables

6 P1 CONN_01X06 Matches official FTDI cable pinout USB
VBUS D- D+ GND


to be used, rather than forcing a on-board chipset GND

Intended for retail converter modules/cables

6 P4 CONN_01X06 Matches official FTDI cable pinout USB
VBUS D- D+ GND












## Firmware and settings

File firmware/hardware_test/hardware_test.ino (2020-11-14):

#include "io_abstraction.h"
#include "mux_control.h"
#include "networking.h"
#include "supervisor.h"

#define PIN_LED_ONBOARD 13
#define PIN_BUTTON_0 27
#define PIN_BUTTON_1 12

#define PIN_MCP23008_INT 32
#define PIN_MCP23008_RESET 14

#define BUTTON_DEBOUNCE_MS 30

bool     button_0_pressed = 0;
bool     button_1_pressed = 0;
uint32_t button_0_timestamp = 0;
uint32_t button_1_timestamp = 0;

void IRAM_ATTR button_0_isr() 
{
    button_0_pressed = true;
    button_0_timestamp = millis();
}

void IRAM_ATTR button_1_isr() 
{
    button_1_pressed = true;
    button_1_timestamp = millis();
}

void setup_pins( void )
{
    pinMode(PIN_LED_ONBOARD, OUTPUT);
    digitalWrite(PIN_LED_ONBOARD, HIGH);

    pinMode(PIN_BUTTON_0, INPUT_PULLUP);
    pinMode(PIN_BUTTON_1, INPUT_PULLUP);

    attachInterrupt( digitalPinToInterrupt(PIN_BUTTON_0), button_0_isr, FALLING );
    attachInterrupt( digitalPinToInterrupt(PIN_BUTTON_1), button_1_isr, FALLING );

    pinMode(PIN_MCP23008_RESET, OUTPUT);
    digitalWrite(PIN_MCP23008_RESET, HIGH);   // Ensure the IO expanders aren't held in reset
    pinMode(PIN_MCP23008_INT,   INPUT);
}


void setup( void ) 
{
    Serial.begin(115200);

    setup_pins();
    io_abstraction_setup_pins();

    supervisor_load_configuration();
    setup_ethernet();

}

void loop( void ) 
{
    handle_ethernet();
    handle_button();
}


void handle_button( void )
{
    if( button_0_pressed )
    {
        if( digitalRead(PIN_BUTTON_0) == LOW )
        {
            if( millis() - button_0_timestamp >= BUTTON_DEBOUNCE_MS )
            {
                button_0_timestamp = millis();
                button_0_pressed = false;
                supervisor_user_change_adapter();
            }
        }
        else
        {
           button_0_pressed = false;
        }
    }

    if( button_1_pressed )
    {
        if( digitalRead(PIN_BUTTON_1) == LOW )
        {
            if( millis() - button_1_timestamp >= BUTTON_DEBOUNCE_MS )
            {
                button_1_timestamp = millis();
                button_1_pressed = false;

                supervisor_user_change_target();
            }
        }
        else
        {
           button_1_pressed = false;
        }

    }
}

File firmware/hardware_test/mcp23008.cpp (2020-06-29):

#include "mcp23008.h"

#include "Arduino.h"
#include <Wire.h>

/* ----- Defines ------------------------------------------------------------ */

/** WARNING **/
/** The register definitions below assume that the MCP23017 operates in
 *  BANKED mode. The device needs to be configured for this mode with the
 *  high bit set in the MCP23_REG_IOCON register. The device appears to
 *  power up in a non-banked 16-bit mode where IOCON register is located
 *  at address 0x0A. So a write to 0x0A with 0x80 is needed to get the device
 *  in banked mode.
 */

#define MCP230XX_BASE_A              (0x00) // MCP23008 & MCP23017 Regs A
#define MCP230XX_BASE_B              (0x10) //            MCP23017 Regs B

#define MCP23_REG_IODIR              (0x00)
#define MCP23_REG_IPOL               (0x01)
#define MCP23_REG_GPINTEN            (0x02)
#define MCP23_REG_DEFVAL             (0x03)
#define MCP23_REG_INTCON             (0x04)
#define MCP23_REG_IOCON              (0x05)
#define MCP23_REG_GPPU               (0x06)
#define MCP23_REG_INTF               (0x07)
#define MCP23_REG_INTCAP             (0x08)
#define MCP23_REG_GPIO               (0x09)
#define MCP23_REG_OLAT               (0x0A)


#ifndef _BV
  #define _BV(bit)         (1UL<<(bit))
#endif

/* -------------------------------------------------------------------------- */

static uint8_t
mcp23008_register_write( const uint8_t i2c_address,
                         const uint8_t i2c_register,
                         const uint8_t i2c_value );

static uint8_t
mcp23008_register_read( const uint8_t i2c_address,
                        const uint8_t i2c_register );

static void 
mcp23008_init_as_input( const uint8_t addr, const uint8_t pin );

static void 
mcp23008_init_as_input_with_pullup( const uint8_t addr, const uint8_t pin );

static void 
mcp23008_init_as_output_pp( const uint8_t addr, const uint8_t pin, const bool initial_state );

/* -------------------------------------------------------------------------- */

/** Init the pin on a given port. Port must be an I2C device */

void
mcp23008_init(  const uint8_t addr,
                const uint8_t pin,
                const MCP23008_IO_MODES mode,
                const bool   initial_state )
{
    switch( mode )
    {
        case _MCP23008_MODE_INPUT:
            mcp23008_init_as_input( addr, pin );
            break;

        case _MCP23008_MODE_INPUT_PU:
            mcp23008_init_as_input_with_pullup( addr, pin );
            break;

        case _MCP23008_MODE_OUTPUT:
            mcp23008_init_as_output_pp( addr, pin, initial_state );
            break;
    }
}

/* -------------------------------------------------------------------------- */

/** Return true when input pin is high, false when input is low */

bool
mcp23008_read_pin(  const uint8_t addr,
                    const uint8_t pin )
{
    const uint8_t base        = (pin <= 7) ? MCP230XX_BASE_A
                                           : MCP230XX_BASE_B;
    const uint8_t pin_mask    = (pin <= 7) ? (uint8_t)_BV( pin ) 
                                           : (uint8_t)_BV(pin - 8 );

    uint8_t value = 0xFF;   // Expect a valid return to change this to non-FF

    value = mcp23008_register_read( addr, (uint8_t)(base + MCP23_REG_GPIO) );

    return ( value & pin_mask ) > 0;
}

/* -------------------------------------------------------------------------- */

/** Set output pin high when on = true, low when on = false */

void
mcp23008_write_pin( const uint8_t addr,
                    const uint8_t pin,
                    const bool    on )
{
    const uint8_t base        = (pin <= 7) ? MCP230XX_BASE_A
                                           : MCP230XX_BASE_B;
    const uint8_t pin_mask    = (pin <= 7) ? (uint8_t)_BV( pin ) 
                                           : (uint8_t)_BV(pin - 8 );

    uint8_t value = 0;
    value = mcp23008_register_read( addr, (uint8_t)(base + MCP23_REG_OLAT) );

    if( on )
    {
        value = (uint8_t)(value | pin_mask);
    }
    else
    {
        value = (uint8_t)(value & ~pin_mask);
    }

    mcp23008_register_write( addr, (uint8_t)(base + MCP23_REG_GPIO), value );
}

/* -------------------------------------------------------------------------- */

/** Toggle the current output state */

void
mcp23008_toggle_pin( const uint8_t addr,
                     const uint8_t pin )
{
    bool state = mcp23008_read_pin( addr, pin );
    mcp23008_write_pin( addr, pin, !state );
}


/* -------------------------------------------------------------------------- */


/* -------------------------------------------------------------------------- */

/** Abstracts I2C register write operation from rest of driver */

static uint8_t
mcp23008_register_write( const uint8_t i2c_address,
                         const uint8_t i2c_register,
                         const uint8_t i2c_value )
{
    Wire.beginTransmission( i2c_address );
    Wire.write( i2c_register );
    Wire.write( i2c_value );
    Wire.endTransmission();

    Wire.requestFrom( i2c_address, 1, true );

    return Wire.read();
}

/* -------------------------------------------------------------------------- */

/** Abstracts I2C register read operation from rest of driver */

static uint8_t
mcp23008_register_read( const uint8_t i2c_address,
                        const uint8_t i2c_register )
{
    uint8_t value = 0;

    Wire.beginTransmission( i2c_address );
    Wire.write( i2c_register );
    Wire.endTransmission();

    Wire.requestFrom( i2c_address, 1, true );
    value = Wire.read();

    return value;
}

/* -------------------------------------------------------------------------- */

static void 
mcp23008_init_as_input( const uint8_t addr, 
                        const uint8_t pin )
{
    const uint8_t base        = (pin <= 7) ? MCP230XX_BASE_A
                                           : MCP230XX_BASE_B;
    const uint8_t pin_mask    = (pin <= 7) ? (uint8_t)_BV( pin )
                                           : (uint8_t)_BV( pin - 8 );

    uint8_t iodir = 0;
    iodir = mcp23008_register_read( addr, base + MCP23_REG_IODIR );
    iodir |= pin_mask; /* IODIR bits as 1 are input */
    mcp23008_register_write( addr, base + MCP23_REG_IODIR, iodir );

    uint8_t gppu = 0;
    gppu = mcp23008_register_read( addr, (uint8_t)(base + MCP23_REG_GPPU) );
    gppu = (uint8_t)(gppu & ~pin_mask); /* GPPU bits as 0 are without pull up */
    mcp23008_register_write( addr, (uint8_t)(base + MCP23_REG_GPPU), gppu );
}

/* -------------------------------------------------------------------------- */
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

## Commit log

2020-05-16 Started schematic
    [hardware.kicad_pcb, hardware.sch, serial_matrix.sch]
2020-05-16 Continued schematic
    [supervisor.sch]
2020-05-17 Schematic capture continued
    [hardware.sch, serial_matrix.sch, supervisor.sch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]
2020-05-17 Moving top level items into sub-pages
    [hardware.sch, serial_matrix.sch, supervisor.sch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]
2020-05-19 Misc cleanup
    [hardware.sch, serial_matrix.sch]
2020-05-19 USB hub and supervisor pinouts
    [hardware.sch, serial_matrix.sch, supervisor.sch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]
2020-05-20 Started layout concepts
    [dut.sch, hardware.kicad_pcb, hardware.sch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]
2020-05-20 Layout continued, minor repinning
    [hardware.kicad_pcb, serial_matrix.sch]
2020-05-23 Continued procrastinating layout and sch changes
    [dut.sch, hardware.kicad_pcb, hardware.sch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]
2020-05-27 Added power switch output filters to sch
    [dut.sch, hardware.kicad_pcb, usb_serial.sch]
2020-05-27 Removed USB hub, sch rework
    [dut.sch, hardware.kicad_pcb, hardware.sch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]
2020-05-28 Repinning, bulk of parts placed, started routing
    [dut.sch, hardware.kicad_pcb, hardware.sch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]
2020-05-28 Continued routing and layout tweaks
    USB section mostly laid out
    [dut.sch, hardware.kicad_pcb, hardware.sch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]
2020-05-29 Continued routing
    [hardware.kicad_pcb]
2020-05-31 Repinned USB power control lines and continued routing
    [hardware.kicad_pcb, hardware.sch]
2020-05-31 Routed all serial lines, cleanup
    [hardware.kicad_pcb]
2020-06-01 Routed I2C lines
    [hardware.kicad_pcb]
2020-06-01 Routing nearly complete
    [hardware.kicad_pcb, usb_input.sch]
2020-06-02 Added 3v3 regulator
    [hardware.kicad_pcb, usb_input.sch]
2020-06-03 Routing cleanup
    [hardware.kicad_pcb, hardware.sch]
2020-06-03 Added switchable loopback to serial mux
    [hardware.kicad_pcb, serial_matrix.sch, supervisor.sch]
2020-06-03 Cosmetics, routing cleanup, etc
    [hardware.kicad_pcb, hardware.sch, supervisor.sch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]
2020-06-04 Cosmetics, routing, pour cleanup
    [hardware.kicad_pcb]
2020-06-05 Pour cleanup, stitching vias
    [hardware.kicad_pcb]
2020-06-08 Readme updates based on parts purchases
    [hardware.kicad_pcb]
2020-06-09 Annotated PCB render, README updates
2020-06-11 Titleblock cleanup
    [dut.sch, hardware.kicad_pcb, hardware.sch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]
2020-06-11 Generated gerbers
    [hardware-B_Cu.gbr, hardware-B_Mask.gbr, hardware-B_Paste.gbr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]
2020-06-26 Fixed USB port label mix-up on main sch
    [hardware.sch]
2020-06-26 Wrote driver for MCP23008 I2C expanders
2020-06-27 Fixed labelling confusion on serial matrix schematic
    [serial_matrix.sch]
2020-06-28 Started adding ethernet support
    Also added helper functions for status led access, ability to clear power or mux configurations.
2020-06-28 Rough REST API for choosing adapters and test devices
    Hacky hard-coded strings for requests to prove concept and allow test framework development
2020-06-29 Returns errors on invalid route,GET or PATH
    [networking.cpp]
2020-07-01 Fleshed out GET/POST control handling
    Ability to GET info by board label or human-friendly names for adapters and targets, full lists.
    Ability for supervisor's responses to trickle back up to networking response for better returns.
    Cleanup.
2020-07-02 Documentation of current GET/POST API
2020-07-03 Stores/loads user-configurable human-readable names for devices
    Starting towards removal of hardcoded device naming requirement.
2020-07-05 Added configurable board name field
2020-11-14 User button to manually set the adapter or target selection
    Basic button handler, ability to override the USB and DUT power/matrix selections.
2020-11-14 Added LED status indication of ethernet state
    Yellow/Green status leds display if ethernet started correctly
    [networking.cpp]
